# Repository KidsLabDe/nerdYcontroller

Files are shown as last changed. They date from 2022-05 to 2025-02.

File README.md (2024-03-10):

# Innovative Lernplatine mit Raspberry Pi Pico für angehende Programmierer

Diese benutzerfreundliche Platine ist speziell darauf ausgelegt, einen Raspberry Pi Pico aufzunehmen, und bietet eine interaktive Plattform, um die Grundlagen der Programmierung und Elektronik spielerisch zu erlernen.

**Hauptmerkmale:**

- **Vielseitiger Raspberry Pi Pico-Sockel:** Im Herzen der Platine befindet sich ein dedizierter Sockel, der perfekt für den Raspberry Pi Pico geeignet ist. Dies ermöglicht eine einfache Integration und eine robuste Verbindung.

- **Farbenfrohe LED-Anzeige:** Ausgestattet mit vier leuchtenden LEDs in verschiedenen Farben, bietet unsere Platine eine visuelle Rückmeldung für Programmierprojekte. Diese LEDs können für eine Vielzahl von Projekten programmiert werden, von einfachen Blinkmustern bis hin zu komplexeren Sequenzen.

- **Integrierter Neigungssensor:** Mit dem eingebauten Neigungssensor können Nutzer Bewegung und Ausrichtung in ihre Projekte einbeziehen. Dieser Sensor eröffnet spannende Möglichkeiten für interaktive Spiele und Experimente.

- **Kompakter Lautsprecher:** Ein kleiner, aber leistungsstarker Lautsprecher ermöglicht es, akustische Elemente in Projekte zu integrieren. Von einfachen Tonsignalen bis hin zu komplexen Melodien können die Nutzer ihre Kreativität voll ausleben.

- **Touch-Sensoren:** Die Platine verfügt über empfindliche Touch-Sensoren, die eine neue Dimension der Interaktivität bieten. Diese können für eine Vielzahl von Anwendungen genutzt werden, von Steuerelementen für Spiele bis hin zu kreativen musikalischen Experimenten.

- **Ideal für DIY-Gamecontroller:** Diese Platine ist nicht nur ein Lernwerkzeug, sondern auch eine Grundlage für den Bau eigener Gamecontroller. Nutzer können die vorhandenen Sensoren und Ausgänge verwenden, um einzigartige und individuelle Spieleerlebnisse zu schaffen.

**Anwendungsbereiche:**

Diese Platine ist ideal für Bildungseinrichtungen, Maker und alle, die einen praktischen und unterhaltsamen Einstieg in die Welt des Programmierens suchen. Sie bietet eine solide Grundlage für Projekte in den Bereichen Robotik, Spieleentwicklung und interaktive Kunst.

# Zusammenbau und erster Start

**Merke: Das Zusammenbauen ist nicht schwer - sie beim Löten zu brennen schmerzt dagegen sehr!** 

Daher immer auf die Finger obacht geben und den Lötkolben sicher ablegen!

## 1. Alles was du brauchst!

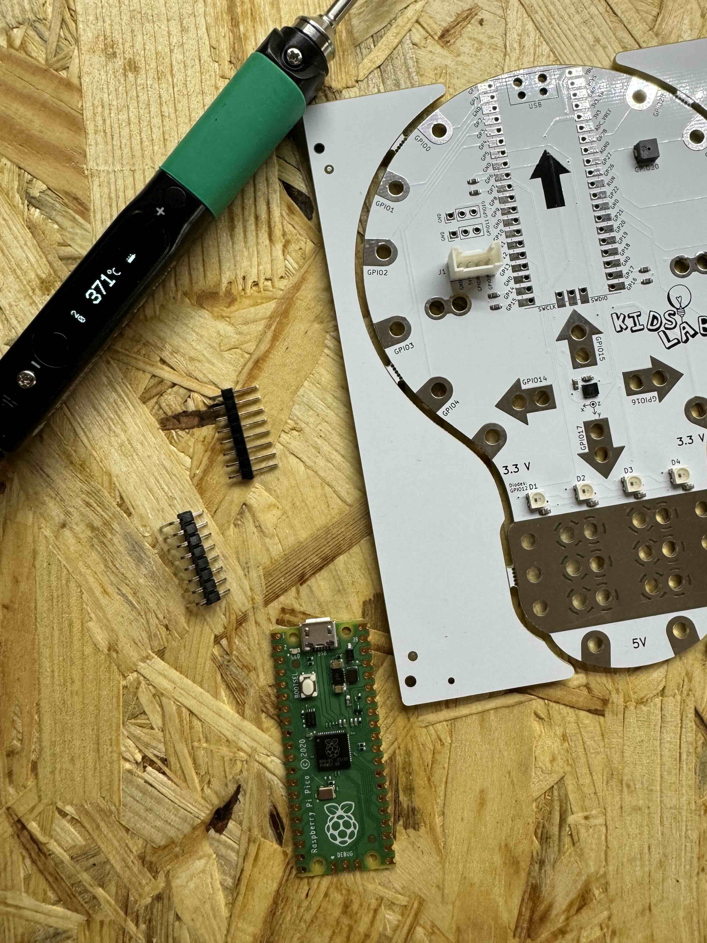
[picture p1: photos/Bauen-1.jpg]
Übersicht der Teile


- Lötkolben, Lötzinn etc.
- 2 "Header" - die nutzen wir, um den Pico richtig auf der Platine zu platzieren. Im Notfall gehen auch 2 Büroklammern...
- einen [Raspberry Pico](https://www.berrybase.de/raspberry-pi-pico-rp2040-mikrocontroller-board) (oder [Pico W](https://www.berrybase.de/raspberry-pi-pico-w-rp2040-wlan-mikrocontroller-board))

## 2. Richtig platzieren

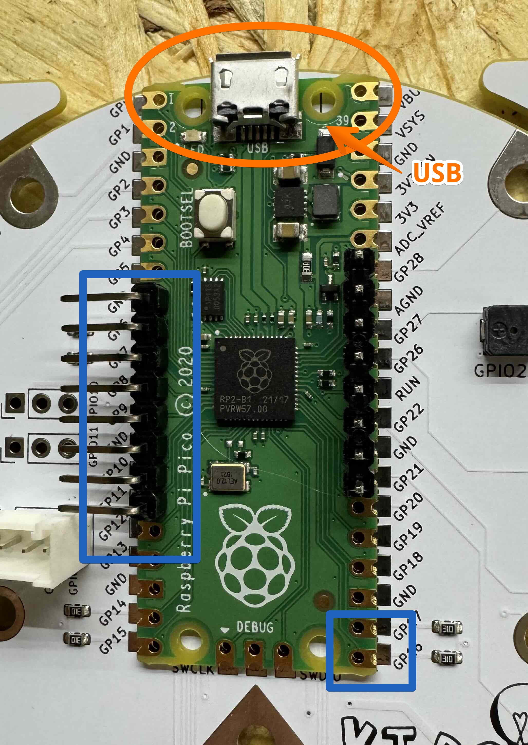
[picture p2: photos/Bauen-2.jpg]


Lege den Pico auf die Platine. 

** Achtung - der USB-Stecker muss oben sein! **

Bitte achte auch darauf, dass der Pico nicht verschoben ist.

## 3. Let's Löt!

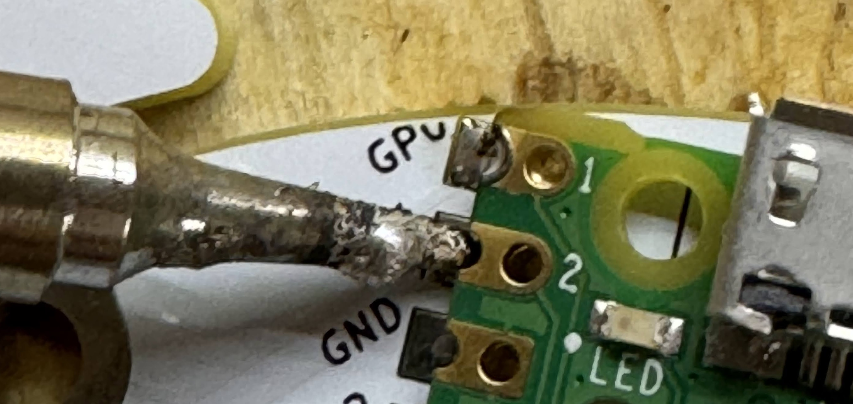
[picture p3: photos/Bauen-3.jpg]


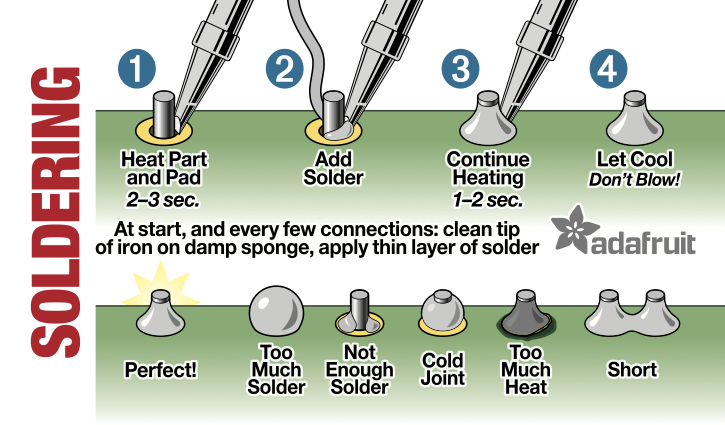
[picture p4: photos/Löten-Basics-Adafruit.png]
Lötes Basics

(Danke an Adafruit!)

- Lötkolben aufheizen
- Lötstelle mit Spitze berühren - am besten vor der Seite
- Etwas lötzinn zugeben
- 2-3 Sekunden warten!
- Jetzt etwas mehr Lötzinn von oben zugeben, es schmilzt an der Platine

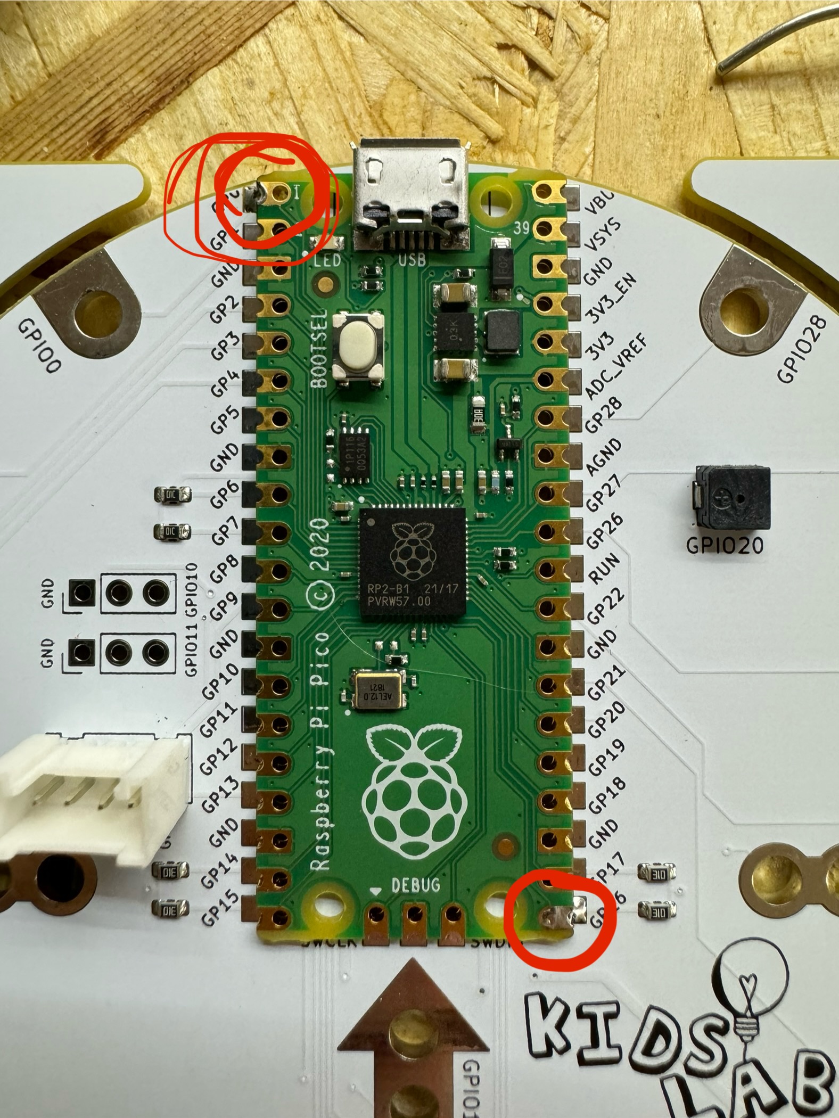
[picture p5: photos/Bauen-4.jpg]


Zuerst 2-3 Pins anlöten, zum Beispiel links oben und rechts unten - dann ist der Pico fest und du kannst die Header entfernen.

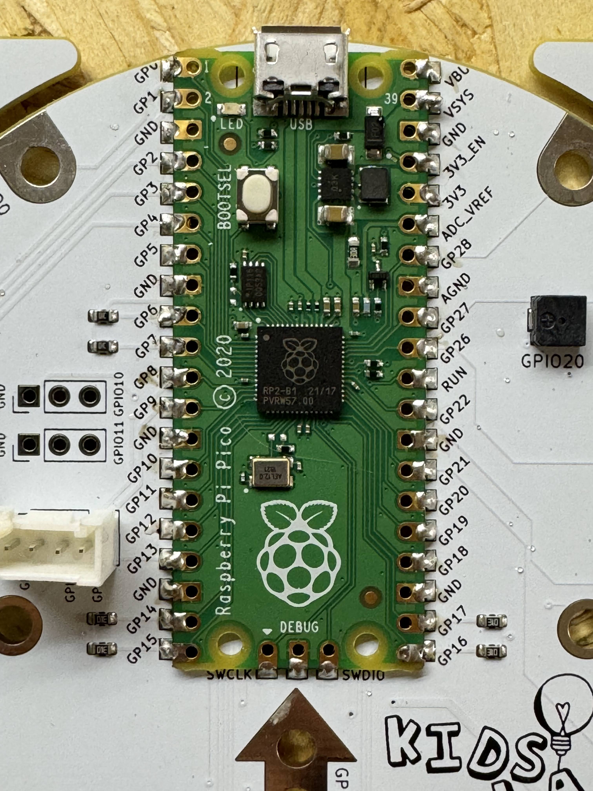
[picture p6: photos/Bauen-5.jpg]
Fertig gelötet


So sieht es aus, wenn alles fertig ist!

## 4. Anschließen und Software aufspielen!

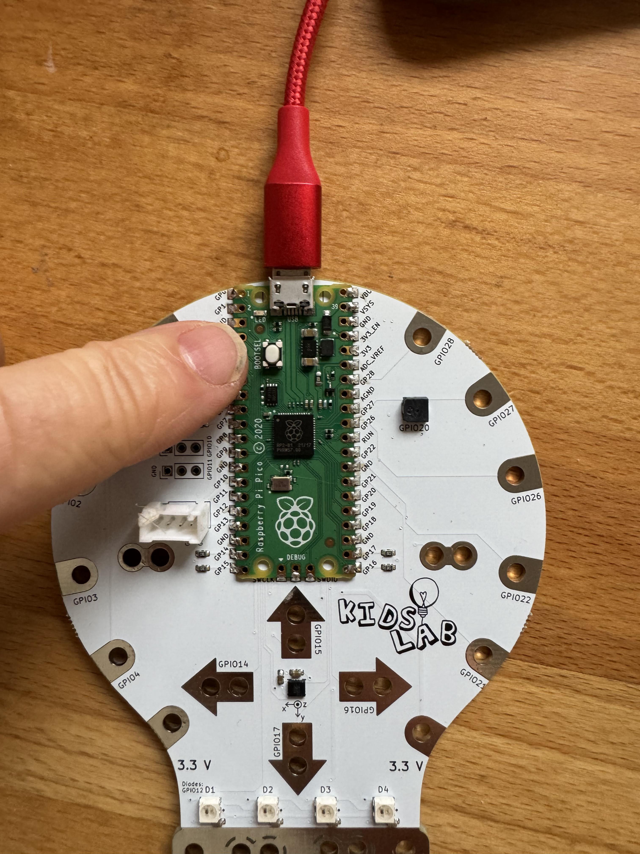
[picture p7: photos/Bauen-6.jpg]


- Stecke den Pico mit einem Micro-USB Kabel am Computer an.
- Wenn er neu ist, sollte er sofort wie ein USB-Stick auftauchen
- Wenn nicht, halte beim Anstecken die kleine weiße Taste "BOOTSEL" gedrückt.

So sieht das auf dem Mac aus:
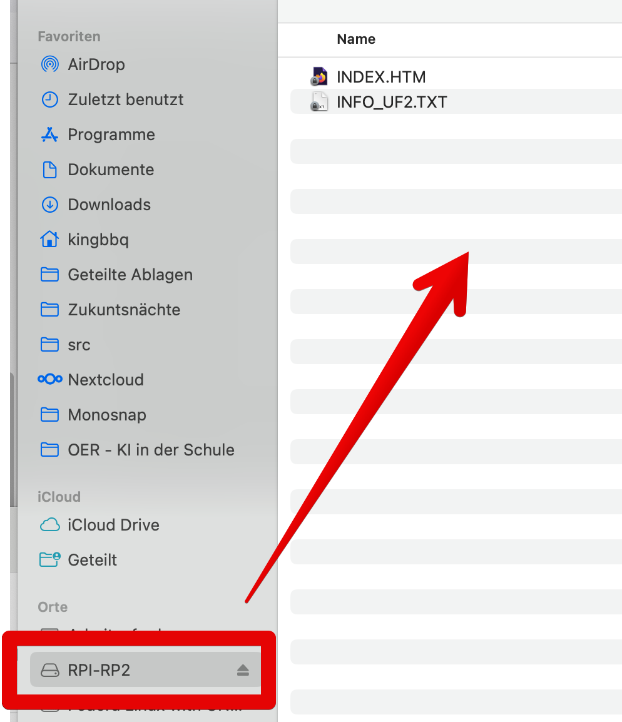
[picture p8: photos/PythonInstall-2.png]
Install 1

(Bei Windows ein bisschen anders...)

Jetzt fehlt nur noch die "Firmware" - das ist die Basis-Software, damit der Pico Python sprechen kann: zusätzlich habe ich noch einen Beispiel-Python-Code drauf gemacht, dass es blinkt etc.

1. Lade diese Datei runter: https://github.com/KidsLabDe/PicoKrokoBirne/blob/main/firmware/PicoKrokoBirne.uf2
2. Kopiere sie auf die Pico im Finder / Explorer. Das geht meistens per Drag&Drop
3. Fertig!

Die PicoKrokoBirne sollte jetzt fröhlich bunt drauf losblinken!

## Anpassen und los programmieren!

Der Pico erscheint nun wiederum als USB-Laufwerk, diesmal heißt er "CIRCUITPY".
Dort findest du die Datei "code.py" - da drin passiert die Magie!

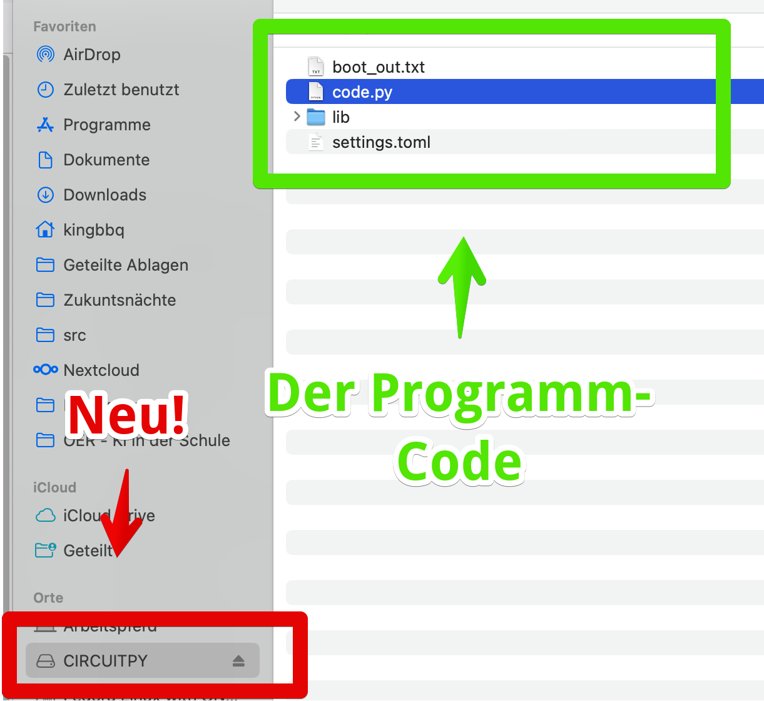
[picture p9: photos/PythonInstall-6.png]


Als Editor empfehle ich dir den Mu-Editor: https://codewith.mu

Viel Spaß!

# Kontaktdaten

Du hast die Glühbirne als Visitenkarte bekommen? Sehr gut! 

Meine Kontaktdaten:

- Gregor Walter
- [gregor@kidslab.de](mailto:gregor@kidslab.de
- Telefon / WhatsApp: 0821-99951920 
- Mehr Infos über das gemeinnützige [KidsLab](https://kidslab.de) 

Ich freue mich auf deinen Anruf / eMail / Nachricht 🤖

Glühbirne-v1

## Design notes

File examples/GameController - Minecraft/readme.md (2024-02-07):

# GameController - Minecraft Version

Dieser Code ist für ein Minecraft-Makro-Keyboard: Du drückst eine Taste und es schickt ein Kommando los, also zum Beispiel um den Gamemode zu wechseln:

`/gamemode 1`

Es wird zusätzlich nach dem "/" für den Kommando-Modus kurz gewartet.

Zum Anpassen der einzelnen Kommandos einfach diesen Teil hier anpassen:

```python
# Hier sind die einzelnen PINS (Tasten)  definiert und die dazu gehörigen Befehle
buttons = {
    board.GP15: "gamemode 1\n",
    board.GP14: "gamemode 2\n",
    board.GP13: "gamemode 3\n",
    board.GP12: "gamemode 4\n",
}
```

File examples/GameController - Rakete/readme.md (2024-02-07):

# GameController - Rakete

Hier ein Beispiel für die Rakete (siehe original: https://github.com/openlab-aux/SchaufensterRakete) - zu sehen im OpenLab zu Augsburg im Schaufenster.

Besonderheiten: 

- Es gibt einen TimeOut - wenn die Rakete 90 Sekenden nicht benutzt wird, wird zuerst 2 mal "enter" gedrückt, um das Spiel wieder zu starten.

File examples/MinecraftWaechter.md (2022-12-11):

# Lautstärkemesser & Minecraft-Abschalter

Wenn wir mit KidsLab in live Minecraft-Workshops machen, wird es manchmal sehr laut: die Emotionen kochen hoch und es ist ja auch alles super aufregend! Aber die Ohren der Mentoren leiden manchmal sehr unter diesen Ausbrüchen.

Daher haben wir mit der PicoKrokoBirne einen Lautstärkemesser erfunden, der automatisch die Emotionen der Kids runterfährt: er friert alle in Minecraft ein, sobald es zu laut wird. Wie das Damals der [Herr Ivan Pertowitsch Pawlow](https://de.wikipedia.org/wiki/Iwan_Petrowitsch_Pawlow) mit seinen Hunden gemacht hat, lassen sich der Geräusch-Ausstoß der Kids vielleicht auch regeln.

## Was brauchst Du?

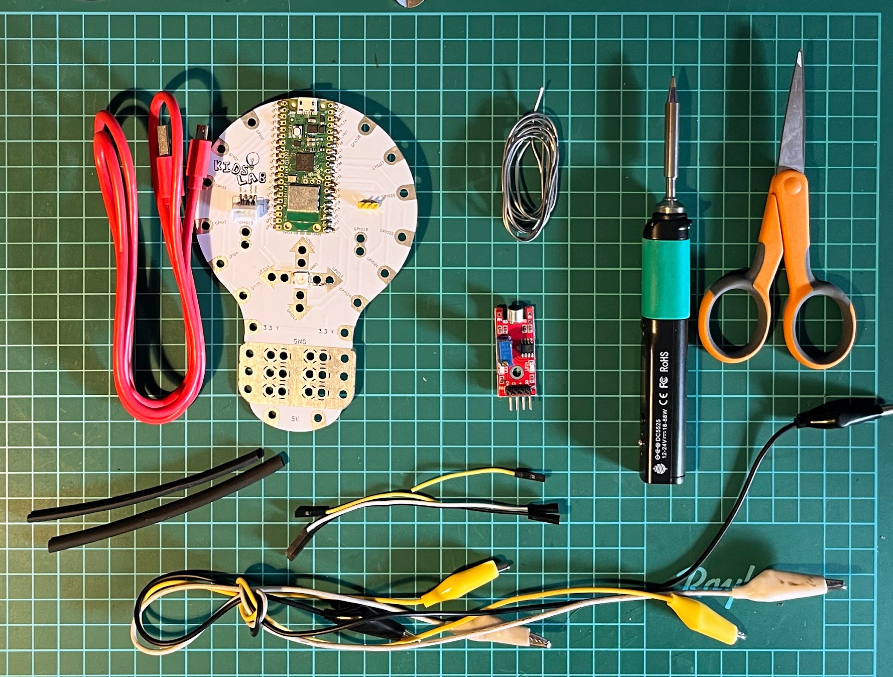
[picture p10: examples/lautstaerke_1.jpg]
lautstaerke_1


### Material

- PicoKrokoBirne mit Raspi Pico
- Lautstärke-Model (z.B. dieses [KY-038](https://sensorkit.joy-it.net/de/sensors/ky-038) gibts zum Beispiel hier: [Amazon AZ KY-038](https://amzn.to/3PhWPC4))
- Krokoklemmen & JumperKabel
- NeoPixel LED (optional)

## Vorbereitung

Bastel Dir aus den Krokoklemmen und JumperKabel die passenden Adapter, um das Lautstärke-Modul an die PicoKrokoBirne anzuschließen:

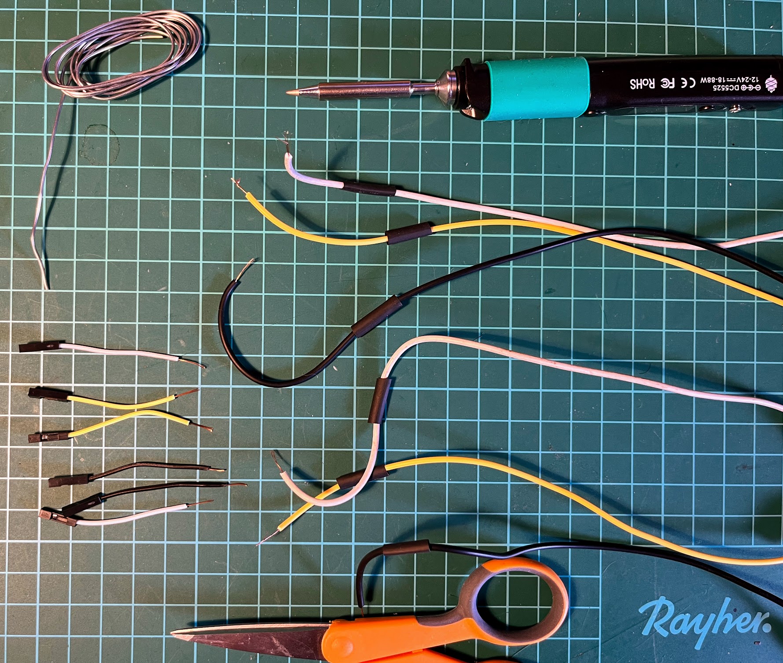
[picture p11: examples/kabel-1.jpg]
kabel-1


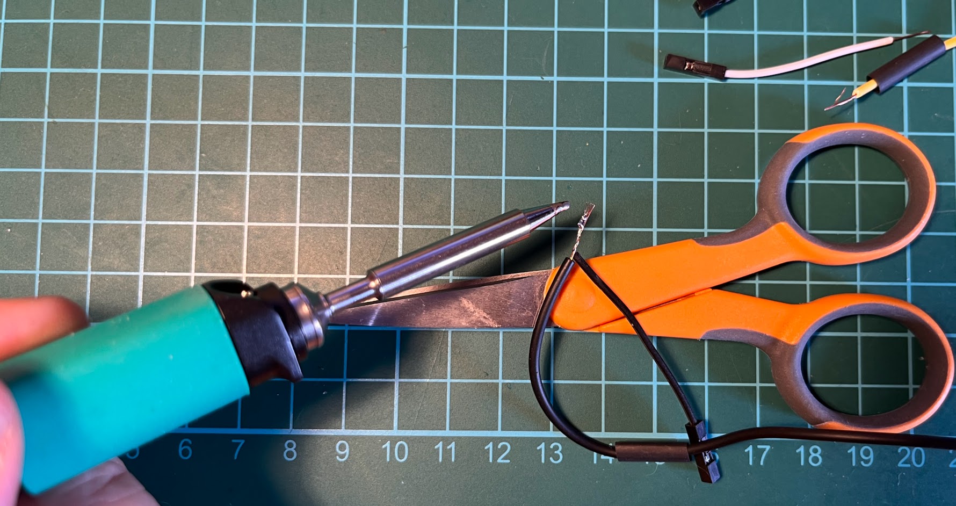
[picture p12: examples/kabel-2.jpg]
kabel-2


## Anschließen

- "+" kommt auf 3.3v
  - Der Sensor kann mit 3.3 oder 5 Volt betrieben werden - es muss aber jeweils die Empfindlichkeit anpassen

- "G" kommt auf GND
- D0 kommt auf einen digitalen Eingang, zum Beispiel GPIO0 

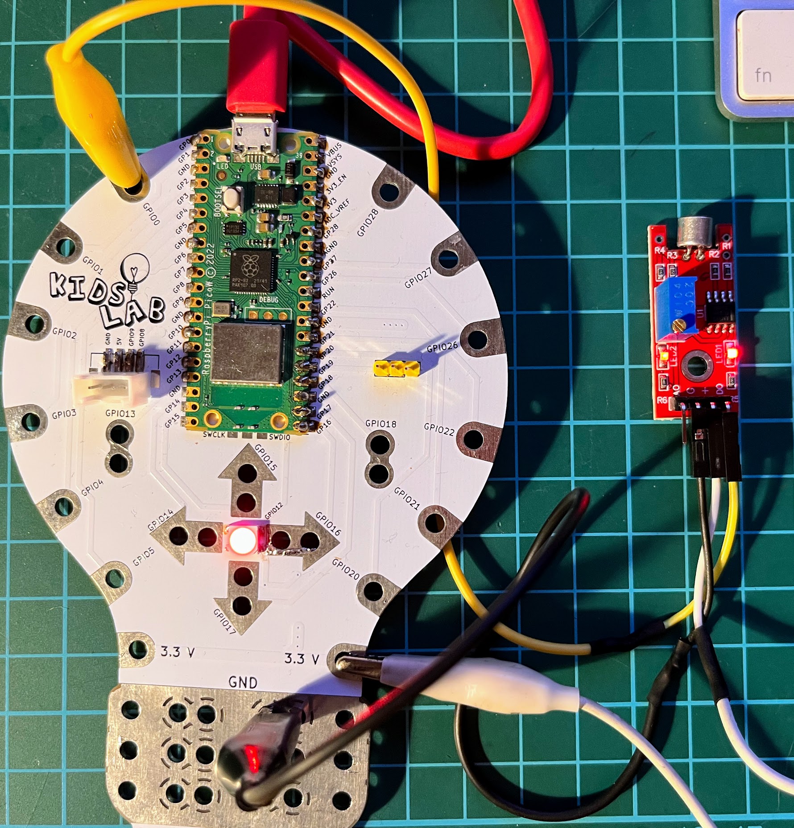
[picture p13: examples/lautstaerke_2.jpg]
lautstaerke_2


## Programmierung

### Lautstärke Messung

Das hat sich schwieriger herausgestellt als gedacht. Der Sensor sollte eigentlich am A0-Anschluss ein analoges Signal liefern: desto lauter, desto höher sollte die Spannung sein. Leider funktionierte das überhaupt nicht wie erwartet. Die Spannung veränderte sich nur sehr wenig, zu wenig, um die Lautstärke vernünftig zu messen.

Zuerst muss ich den Pin einrichten:

```python
import time
import board
from board import *
from digitalio import DigitalInOut, Direction, Pull

switch = DigitalInOut(board.GP0)
switch.direction = Direction.INPUT
switch.pull = Pull.DOWN
```

Der Sensor hat 2 Ausgänge: zusätzlich zu dem analogen auch einen digitalen: über den Dreh-Schalte (Potentiometer) auf der Platine, lässt sich eine Schwelle einstellen. Wenn diese überschritten ist, wird ein digitales Signal (0 Volt, 3,3 Volt) ausgegeben. Wenn man das "sammelt", das heißt über einen bestimmten Zeitraum zusammenzählt, erhält man einen guten Wert.

```python
while True:
		noiseLevel = 0;
    for x in range(100000):
        if switch.value:
            noiseLevel = noiseLevel +1
    if noiseLevel < 500:
        pixels.fill(GREEN)
    elif noiseLevel < 1500:
        pixels.fill(YELLOW)
    elif noiseLevel < 4000:
        pixels.fill(RED)
    else:
        pixels.fill(PURPLE)
    pixels.show()      
```

### Lautstärke kalibieren

Damit der Sensor richtig anspricht, müssen wir ihn noch Kalibrieren, also beibringen, was genau "zu laut" ist:

- Die **LED2** zeigt an, ab der Sensor anschlägt
- An der Schraube auf dem kleinen blauen Kästchen kannst du sie einstellen
- Drehe so lange, bis die LED ausgeht 
- Jetzt vorsichtig sol lange, bis sie blinkt, wenn es laute Geräusche gibt  

### Minecraft User einfrieren

Jetzt fehlt noch noch eines: wenn es zu laut ist, sollen die User in Minecraft eingefroren werden. Das machen wir über die Funktion des Pico, die HID heißt: er kann so tun, als ob er eine Tastatur ist. 

```python
    else:
        pixels.fill(PURPLE)
        typeIt("/der Befehl zum Einfrieren")
```

Die PicoKrokoBirne also nur noch am Rechner der Mentors anschließen - und sobald es zu laut wird....

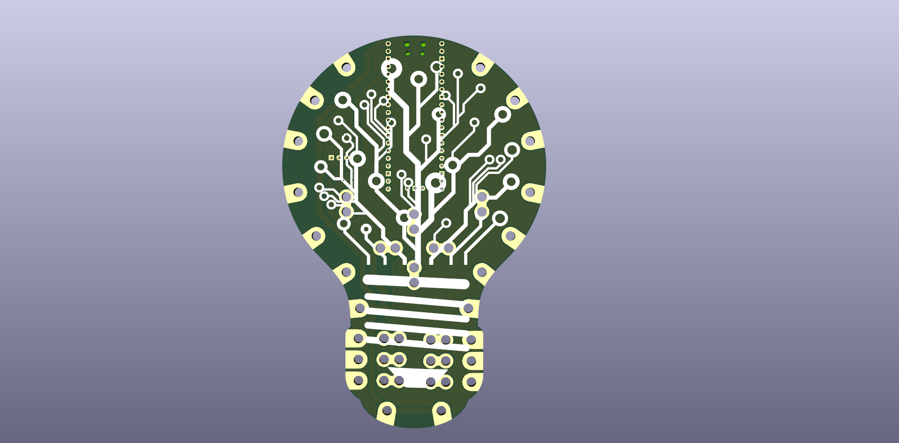
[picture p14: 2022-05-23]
kidslab-lamp_screenshot_backDesign_0.7.png

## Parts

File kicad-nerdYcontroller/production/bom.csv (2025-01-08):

Designator | Footprint | Quantity | Value | LCSC Part #
BZ301 | FUET-5020 | 1 | Buzzer-FUET-5020 | C391029
C101, C113, C114, C304 | 0603 | 4 | 100nF | C14663
C102, C103 | 0603 | 2 | 22pF | C1653
C104, C105, C106, C107, C108, C109, C110, C301, C302, C401, C402, C403, C404, C405, C406, C407, C408, C409, C410, C411, C412, C413, C414, C415, C416, C417, C418, C419, C420, C421, C422, C423, C424, C425 | 0402 | 34 | 100nF | C56392
C111 | 0603 | 1 | 10uF | C96446
C112, C115, C303, C305 | 0603 | 4 | 1uF | C15849
C201, C202 | 0805 | 2 | 10uF | C710989
C203 | 0603 | 1 | 1nF | C1588
D201, D203 | D_SOD-123 | 2 | B5817W | C2909923
D202 | WSON-6_1.5x1.5mm_P0.5mm | 1 | PRTR5V0U2F | C2937001
D301 | 0603 | 1 | KT-0603R | C2286
D401, D402, D403, D404, D405, D406, D407, D408, D409, D410, D411, D412, D413, D414, D415, D416, D417, D418, D419, D420, D421, D422, D423, D424, D425 | LED_WS2812B-2020_PLCC4_2.0x2.0mm | 25 | WS2812B-2020 | C965555
J201 | JST_PH_S2B-PH-SM4-TB_1x02-1MP_P2.00mm_Horizontal | 1 | S2B-PH-SM4-TB | C295747
J301, J302 | PinHeader_2x03_P2.54mm_Vertical_SMD | 2 | Conn_02x03_Odd_Even | C192301
J303 | ZX-HY2.0-4PLT | 1 | ZX-HY2.0-4PLT | C7429562
J304 | SAMTEC_HLE-115-02-F-DV | 1 | HLE-115-02-F-DV
P201 | USB_C_Receptacle_GCT_USB4110 | 1 | USB_C_Plug_USB2.0 | C5143397
Q301 | SOT-23 | 1 | DDTC113ZCA | C151437
R101, R102, R105, R307 | 0603 | 4 | 1k | C21190
R103, R104 | 0603 | 2 | 27R | C25190
R201, R202 | 0603 | 2 | 5k1 | C23186
R203 | 0603 | 1 | 100 | C22775
R301, R302 | 0603 | 2 | 10k | C25804
R303, R304, R305, R306 | 0603 | 4 | 1M | C105578
R308 | 0603 | 1 | 33k | C25593
R309 | 0603 | 1 | 330R | C22104
S101 | SW_TS-1187A-B-A-B | 1 | TS-1187A-B-A-B | C318884
U101 | QFN-56-1EP_7x7mm_P0.4mm_EP3.2x3.2mm | 1 | RP2040
U102 | SOIC-8_5.23x5.23mm_P1.27mm | 1 | W25Q128JVS | C97521
U201 | SOT-223-3_TabPin2 | 1 | AMS1117-3.3 | C6186
U301 | LGA-14_3x2.5mm_P0.5mm_LayoutBorder3x4y | 1 | LSM6DS3TR-C | C967633
U302 | LMA3722T421-OA5 | 1 | LMA3722T421-OA5 | C5373233
Y101 | Crystal_SMD_3225-4Pin_3.2x2.5mm | 1 | Crystal_GND24 | C9002

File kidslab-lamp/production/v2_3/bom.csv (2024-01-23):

Designator | Footprint | Quantity | Value | LCSC Part #
BZ1 | Buzzer-FUET-4020 | 1 | Buzzer-FUET-4020 | C391027
C4, C5, C6, C7, C8, C9 | 0603 | 6 | 100nF | C14663
D1, D2, D3, D4 | WS2812B-Mini | 4 | WS2812B-Mini | C527089
J1 | HY-4A-THT | 1 | HY-4A | C146064
R1, R2, R3, R4 | 0603 | 4 | 1M | C105578
R5, R6 | 0603 | 2 | 10k | C25804
U2 | LGA-14_3x2.5mm_P0.5mm_LayoutBorder3x4y | 1 | LSM6DS3TR-C | C967633

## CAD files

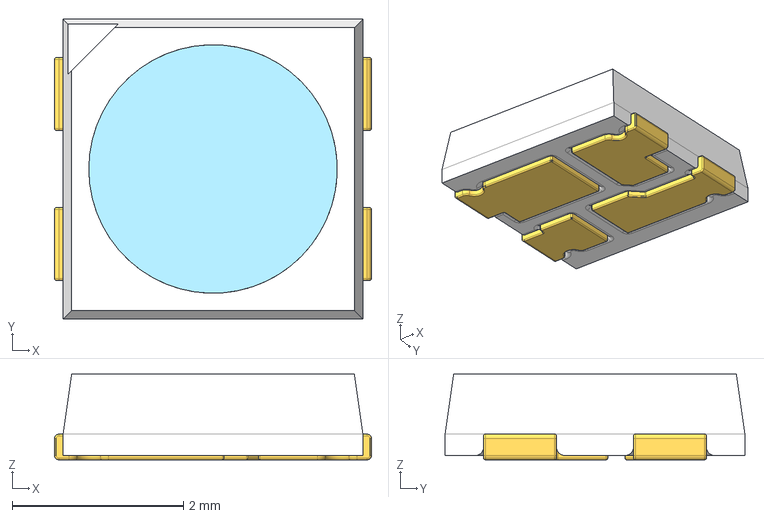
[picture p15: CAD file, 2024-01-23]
kidslab-lamp/3D/SMD3535 RGB.stp
3.70 x 3.50 x 1.00 mm

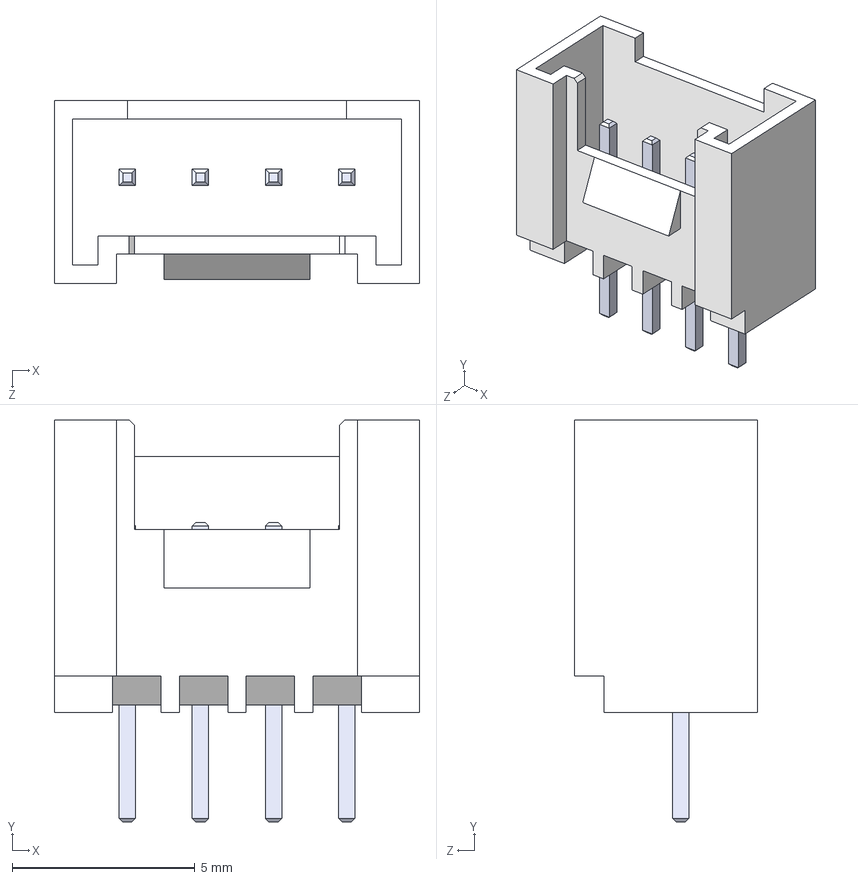
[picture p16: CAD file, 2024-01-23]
kidslab-lamp/3D/Grove Connector.STEP
10.0 x 11.0 x 5.00 mm

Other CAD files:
kidslab-lamp/KiCad-RP-Pico/SketchUp Model/Pico.skp
kidslab-lamp/footprints/KiCad-RP-Pico/SketchUp Model/Pico.skp

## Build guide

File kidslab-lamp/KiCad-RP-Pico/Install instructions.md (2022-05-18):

# Install instructions

## 1. Copy the files locally

Copy the `RP-Pico Libraries` folder wherever you like on your computer.

## 2. Install the Raspberry Pi Pico board schema symbol

Use the `KiCad | Preferences | Manage Symbol Libraries...` command to manage the symbol library:



then select the global tab and click on the folder button:



navigate to the `RP-Pico Libraries` folder, select the `MCU_RaspberryPi_and_Boards.kicad_sym` file and open it:



et voilà, the first step is completed:



You can now close the symbol libraries manager window.

## 3. Install the Raspberry Pi Pico board footprint

You can use a similar approach to add the footprint to the footprint libraries manager, but I've found some issues that I've solved using the footprint editor, so here are the steps I suggest you to follow:

Open the footprint editor



wait for the footprints to load... then use the `File | Add Library` command:



confirm the `Global` choice:



and select the `MCU_RaspberriPi_and_Boards.pretty` folder (yes, the folder represent a footprint library on KiCad):



Now the library is installed on KiCad with the Raspberry Pi Pico footprint (double click on it to see it on the editor pane):



Don't close the windows as the next step start from here.

## 4. Install the Raspberry Pi Pico board footprint 3D visual

If not already open, open the the footprint editor

symbol library manager

double click on the `RPi_Pico_SMD_TH` footprint from the `MCU_RaspberriPi_and_Boards` library and then click on the `Footprint properties` icon:



In the footprint properties window, first select the `3D Settings` tab. Please note that the preview shows only the PCB board with the footprint added on step 3, without any 3D representation of the Raspberry Pi Pico board. Now click on the folder icon to add the 3D model:



Navigate to the `RP-Pico Libraries` folder, select the `Pico.wrl` file and wait until the model is shown in the right panel, then confirm with OK:



The model is already scaled and translated to match the footprint:



now close the `Footprint Properties` window, and the `Footprint Editor`, obviously saving the changes.

## Conclusion

Now that you've installed the schema and footprint and added the 3D model to the footprint, you can use the Raspberry Pi Pico board on your KiCad projects.

I've also added a test KiCad Project on the `Test` folder, that you can use to see an example of it.

Have fun!

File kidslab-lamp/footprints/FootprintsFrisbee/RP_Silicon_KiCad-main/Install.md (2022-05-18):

# Install KiCad libraries

## Manage Symbol Libraries

Accessed from the Preferences menu, add a new line with the +, give it a name and use the folder icon to point to the directory/folder where you have KiCadLibraries.

Manage Symbol Libraries screen shot


## Manage Footprint Libraries

Ditto! Accessed from the Preferences menu, add a new line with the +, give it a name and use the folder icon to point to the directory/folder where you have KiCadLibraries.

Manage Footprint Libraries screen shot


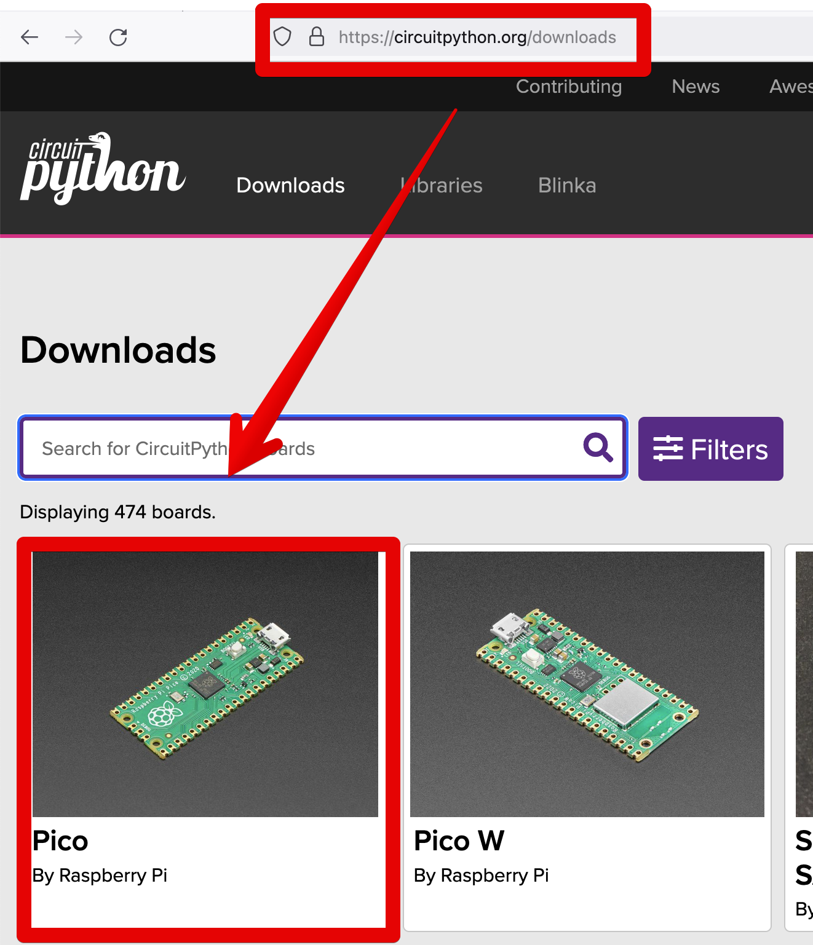
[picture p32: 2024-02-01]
photos/PythonInstall-3.png

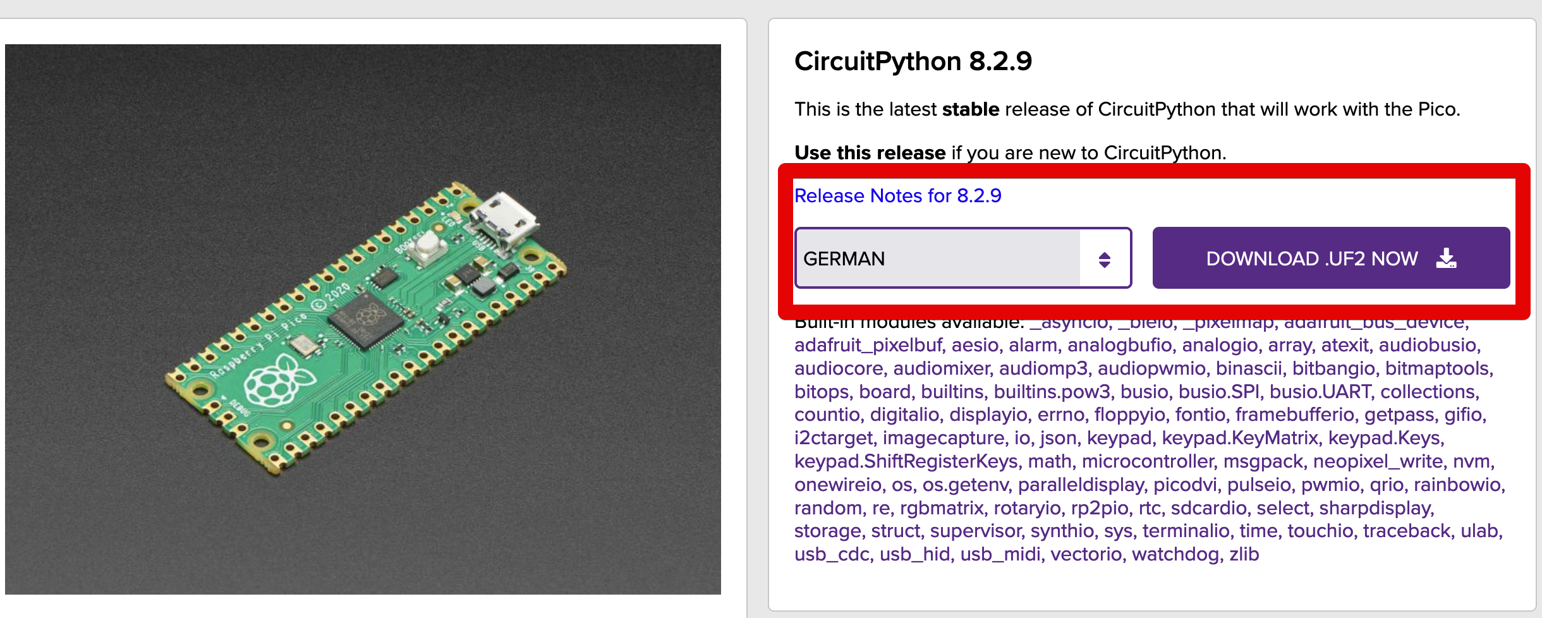
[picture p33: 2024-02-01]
photos/PythonInstall-4.png

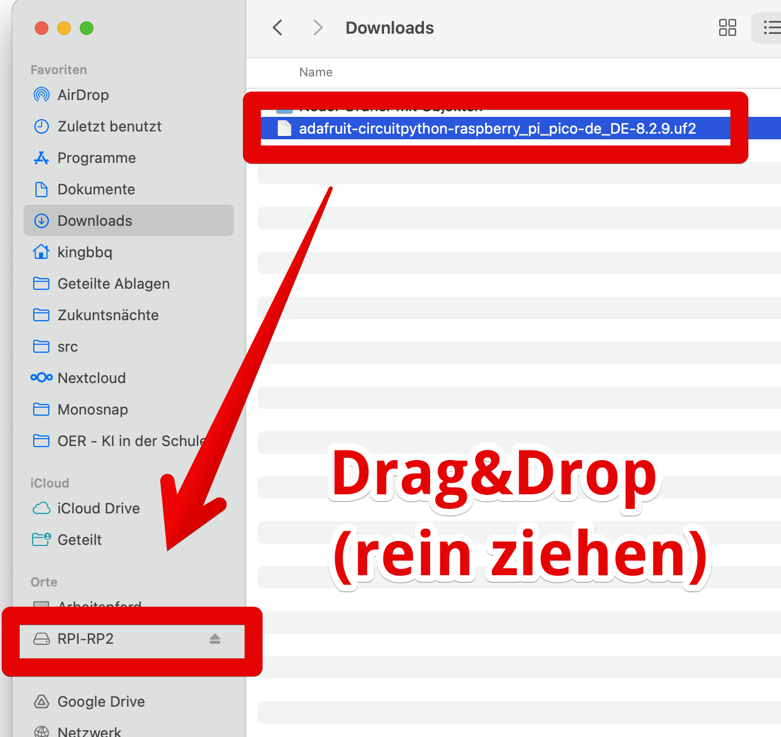
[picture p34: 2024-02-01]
photos/PythonInstall-5.png

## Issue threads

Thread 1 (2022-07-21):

3V / GND very close

KingBBQ, 2022-07-21:
while testing we had a few "shorts" - the 3v pins are very close to the GND plate.

strg-v, 2022-09-11:
Removed GPIO5 & GPIO20 and moved 3.3V up in order to prevent short circuits.

Closed 2022-09-11.

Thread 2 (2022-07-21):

Add QR Code with more info

KingBBQ, 2022-07-21:
Should we use a link like "Kidslab.de/Glühbirne" or the link to the github project? What do you reckon?

KingBBQ, 2022-07-21:
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

strg-v, 2022-09-11:
Added the QR-Code to the right of the Pi-Pico.

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

Closed 2022-09-11.

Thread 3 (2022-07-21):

How to solder the NeoPixel?

KingBBQ, 2022-07-21:
4 pins, it's not clear with pin is which...

strg-v, 2022-09-11:
Added silk screen markings indicated in the [datasheet](https://cdn-shop.adafruit.com/product-files/1138/SK6812+LED+datasheet+.pdf):

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

Closed 2022-09-11.

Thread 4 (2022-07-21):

Add orientation for the Pico

KingBBQ, 2022-07-21:
when soldering the picos to the pcb, 2 times i soldered them with the USB "down". Maybe add a arrow or such, to make the orientation clearer?

strg-v, 2022-09-11:
Added a box indicating the USB port location, as well as a big arrow pointing upwards ;)

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

Closed 2022-09-11.

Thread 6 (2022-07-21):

Add touch pull up resisitors

KingBBQ, 2022-07-21:
see:
https://github.com/microbit-foundation/microbit-v2-hardware/blob/main/V2/MicroBit_V2.0.0_S_schematic.PDF

for the 4 direction pins

strg-v, 2022-09-11:
I added four through hole resistor locations for 10MOhm resistors. R1-R4:

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

Closed 2022-09-11.

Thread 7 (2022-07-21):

2nd Servo connector (optional)

KingBBQ, 2022-07-21:
To be able to connect 2 servos at once over the header pins.

KingBBQ, 2022-07-26:
and please use pins 1-15 for the signal.
PiperMake supports these only in the UI.
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

KingBBQ, 2022-07-28:
testet the servo connection - works like a charm :)

strg-v, 2022-09-11:
I added another PWM connector to GPIO10 and moved the existing one to GPIO11.

Closed 2022-09-11.

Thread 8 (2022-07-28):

Which is the right component for grove?

KingBBQ, 2022-07-28:
this one?
https://www.reichelt.de/arduino-grove-universal-buchse-4-pin-90-10er-pack--grv-connec4pin90-p191136.html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

strg-v, 2022-09-11:
I used this one: https://www.mouser.de/ProductDetail/Seeed-Studio/114020163?qs=7MVldsJ5Uaz48D%2F3kIbRqg%3D%3D

Closed 2022-09-11.

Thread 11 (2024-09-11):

GP statt GPIO / Verwirrend

KingBBQ, 2024-09-11:
auf der platine des pico und im code heißen die Pins immer GP

auf der Glühbirne GPIO - verwirrend?

https://www.elektronik-kompendium.de/sites/raspberry-pi/2611051.htm

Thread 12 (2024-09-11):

Grove stecker - 2 & Belegung

KingBBQ, 2024-09-11:
- aktuell geht das auf GP8 und 9
- da ist aber dein Analog

https://www.elektronik-kompendium.de/sites/raspberry-pi/2611051.htm

ein zusätzlicher anschluss auf 26 / 27 ODER 28?

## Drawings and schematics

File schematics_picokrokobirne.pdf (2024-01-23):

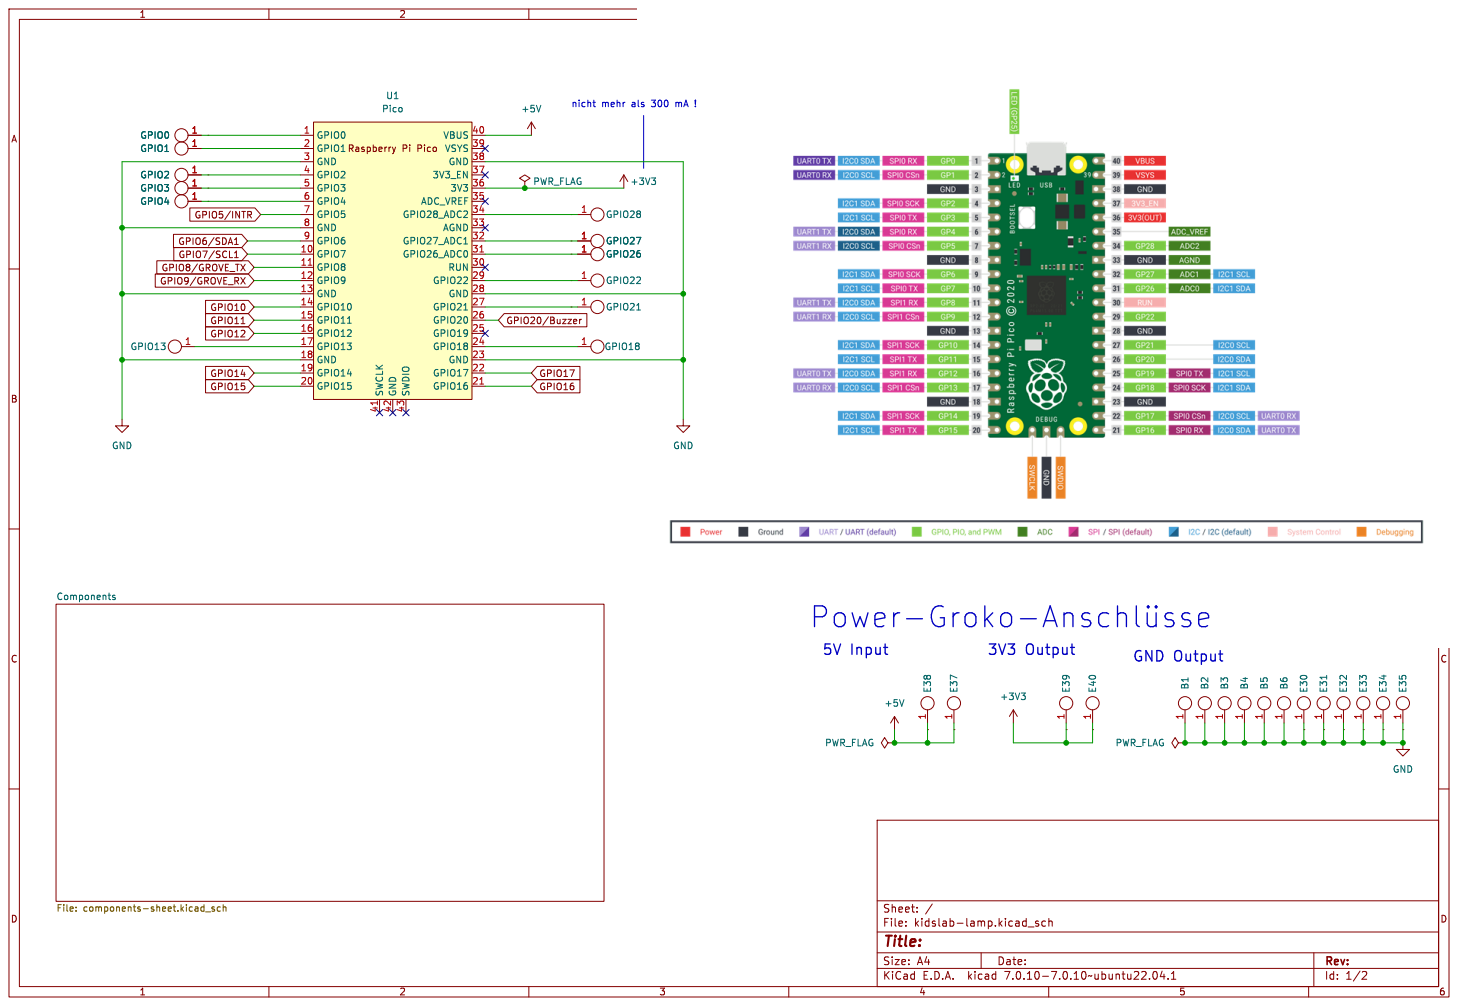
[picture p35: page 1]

Id: 1/2 Title: File: kidslab-lamp.kicad_sch Sheet: / Components File: components-sheet.kicad_sch

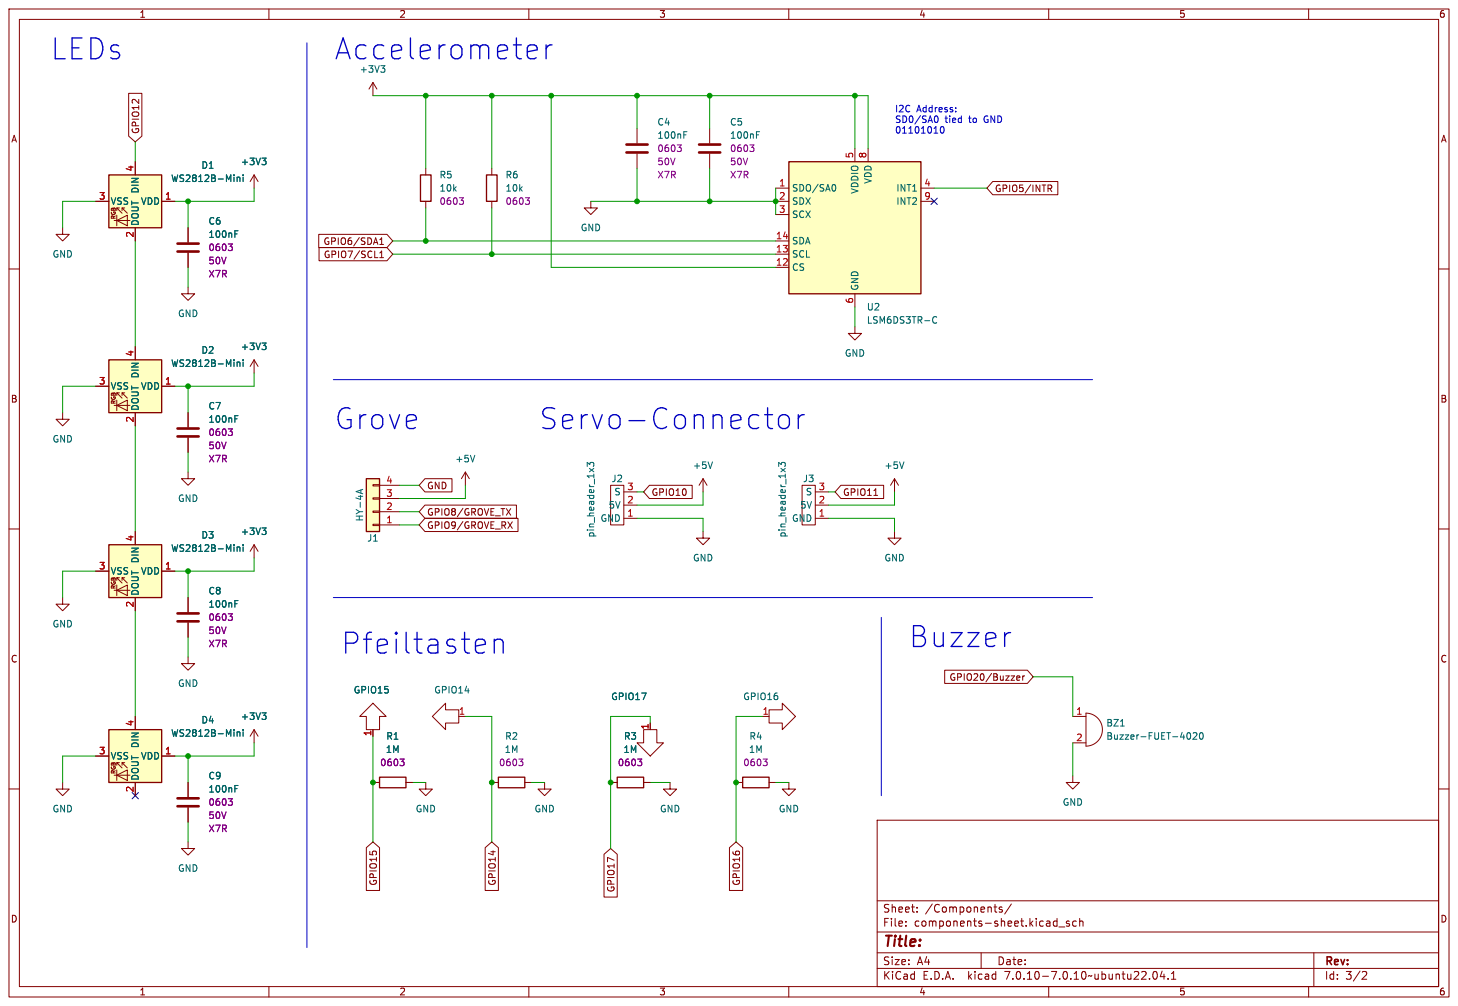
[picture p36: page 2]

I2C Address: SD0/SA0 tied to GND

Id: 3/2 Title: File: components-sheet.kicad_sch Sheet: /Components/

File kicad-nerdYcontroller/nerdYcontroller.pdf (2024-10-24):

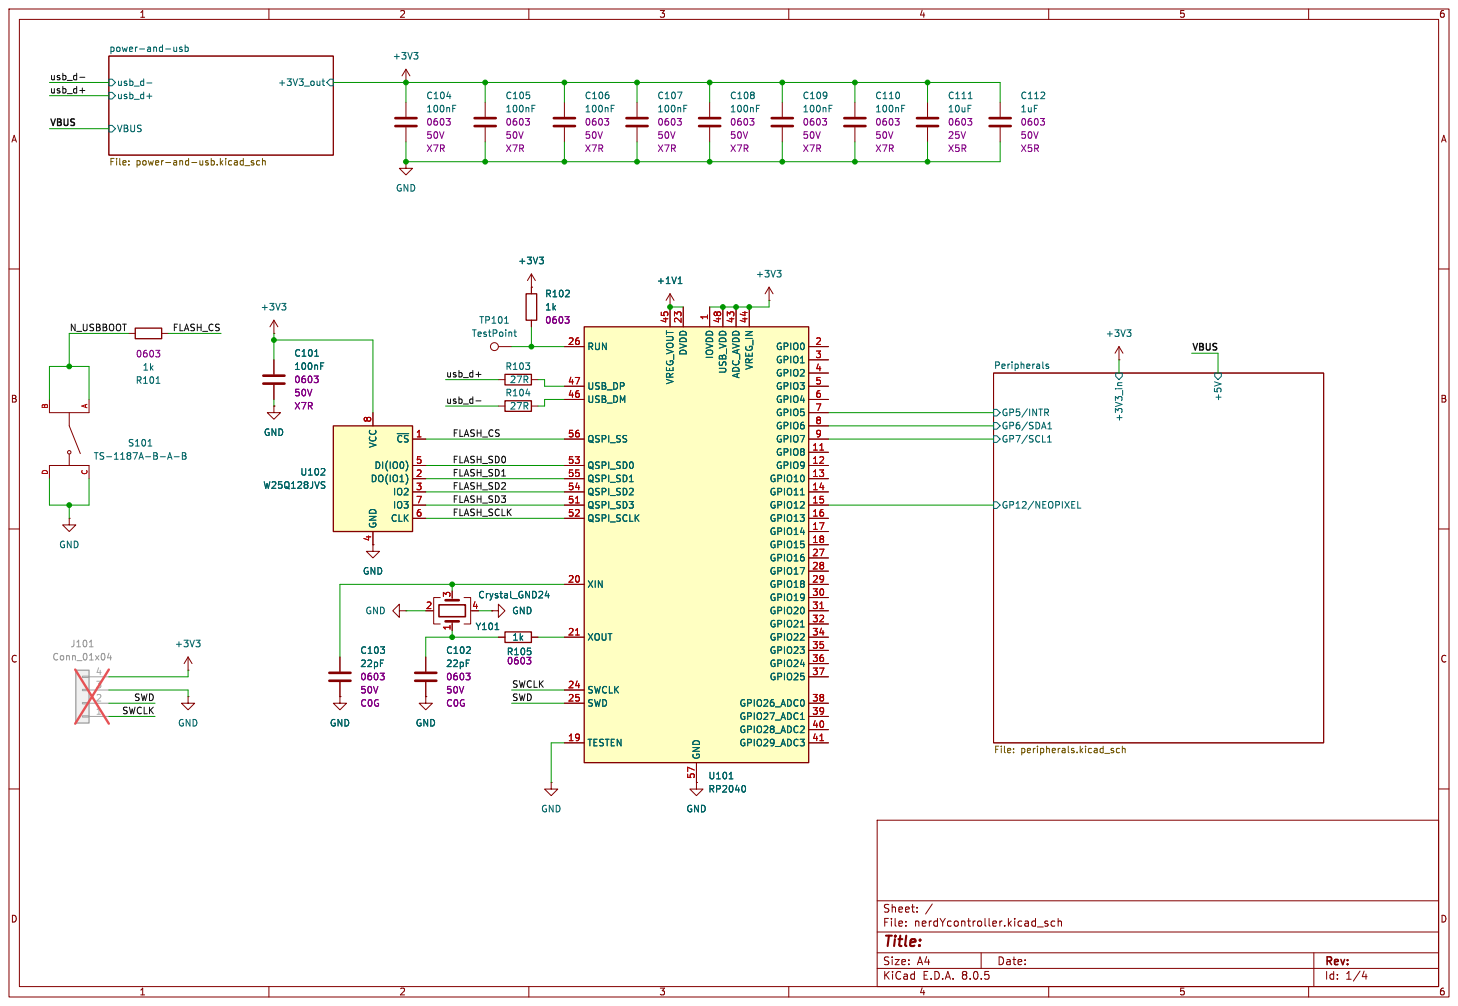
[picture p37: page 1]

1 GPIO8 11 GPIO9 12 GPIO10 13 GPIO11 14 GPIO12 15 GPIO13 16 GPIO14 17 GPIO15 18 TESTEN 19 GPIO0 2 XIN 20 XOUT 21 DVDD 23 SWCLK 24 SWD 25 RUN 26 GPIO16 27 GPIO17 28 GPIO18 29 GPIO1 3 GPIO19 30 GPIO20 31 GPIO21 32 GPIO22 34 GPIO23 35 GPIO24 36 GPIO25 37 GPIO26_ADC0 38 GPIO27_ADC1 39 GPIO2 4 GPIO28_ADC2 40 GPIO29_ADC3 41 ADC_AVDD 43 VREG_IN 44 VREG_VOUT 45 USB_DM 46 USB_DP 47 USB_VDD 48 GPIO3 5 QSPI_SD3 51 QSPI_SCLK 52 QSPI_SD0 53 QSPI_SD2 54 QSPI_SD1 55 QSPI_SS 56 GND 57 GPIO4 6 GPIO5 7 GPIO6 8 GPIO7 9 U101 RP2040 GND

1 GPIO8 11 GPIO9 12 GPIO10 13 GPIO11 14 GPIO12 15 GPIO13 16 GPIO14 17 GPIO15 18 TESTEN 19 GPIO0 2 XIN 20 XOUT 21 DVDD 23 SWCLK 24 SWD 25 RUN 26 GPIO16 27 GPIO17 28 GPIO18 29 GPIO1 3 GPIO19 30 GPIO20 31 GPIO21 32 GPIO22 34 GPIO23 35 GPIO24 36 GPIO25 37 GPIO26_ADC0 38 GPIO27_ADC1 39 GPIO2 4 GPIO28_ADC2 40 GPIO29_ADC3 41 ADC_AVDD 43 VREG_IN 44 VREG_VOUT 45 USB_DM 46 USB_DP 47 USB_VDD 48 GPIO3 5 QSPI_SD3 51 QSPI_SCLK 52 QSPI_SD0 53 QSPI_SD2 54 QSPI_SD1 55 QSPI_SS 56 GND 57 GPIO4 6 GPIO5 7 GPIO6 8 GPIO7 9 GND

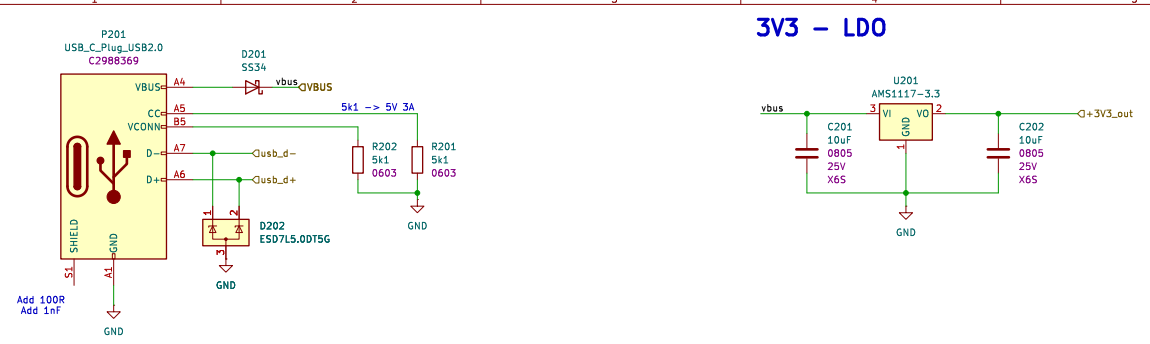
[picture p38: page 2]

Id: 2/4 Title: File: power-and-usb.kicad_sch Sheet: /power-and-usb/

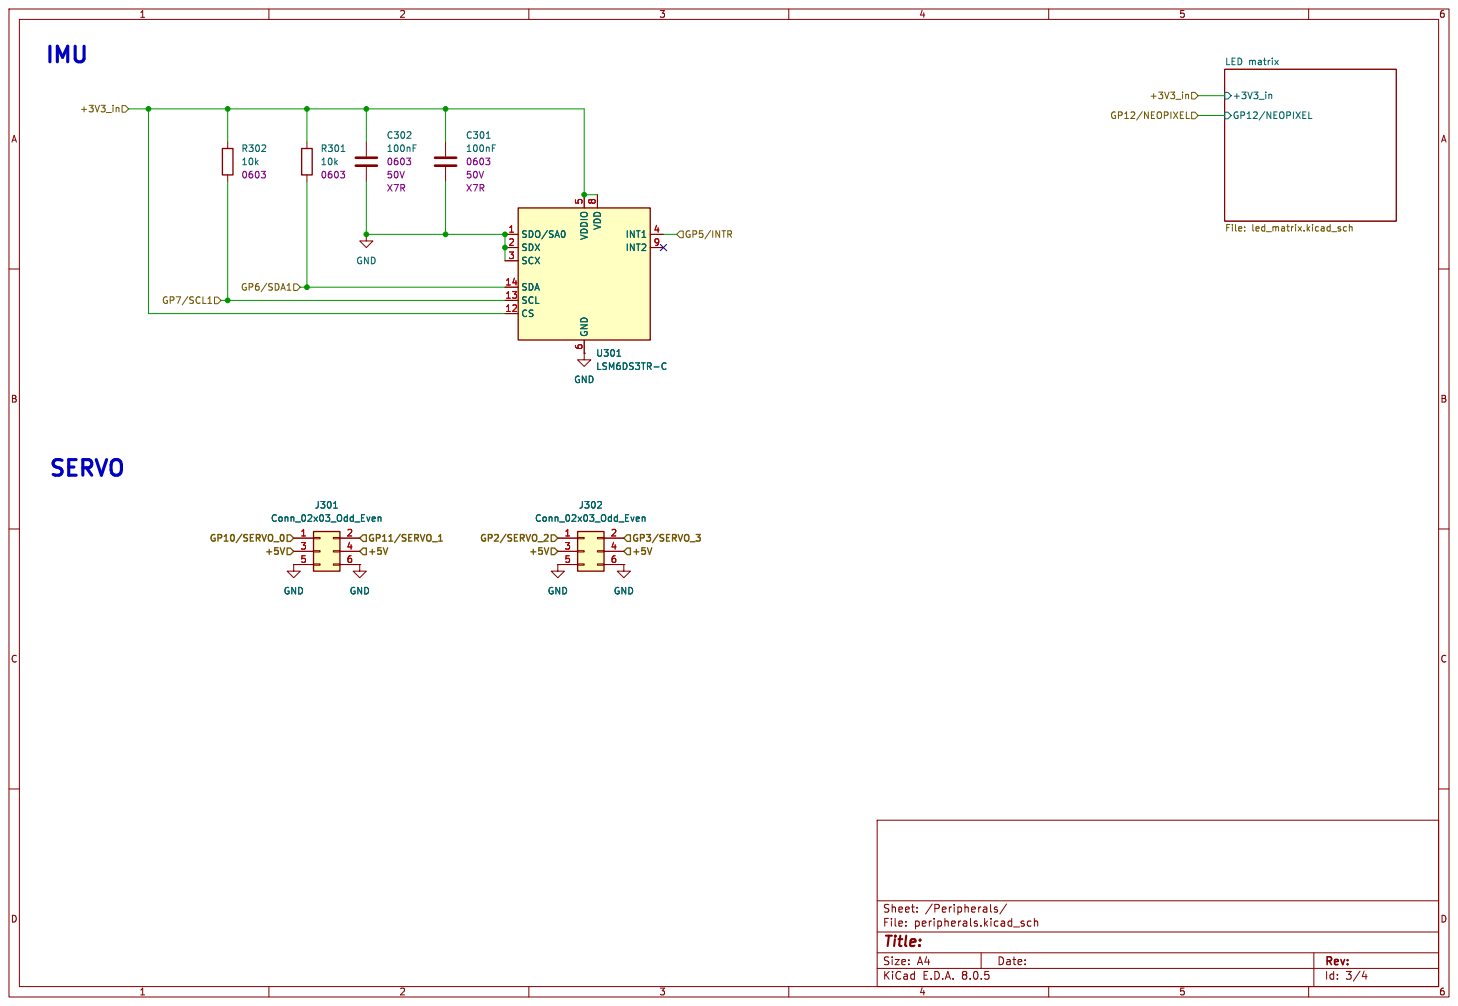
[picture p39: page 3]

Id: 3/4 Title: File: peripherals.kicad_sch Sheet: /Peripherals/

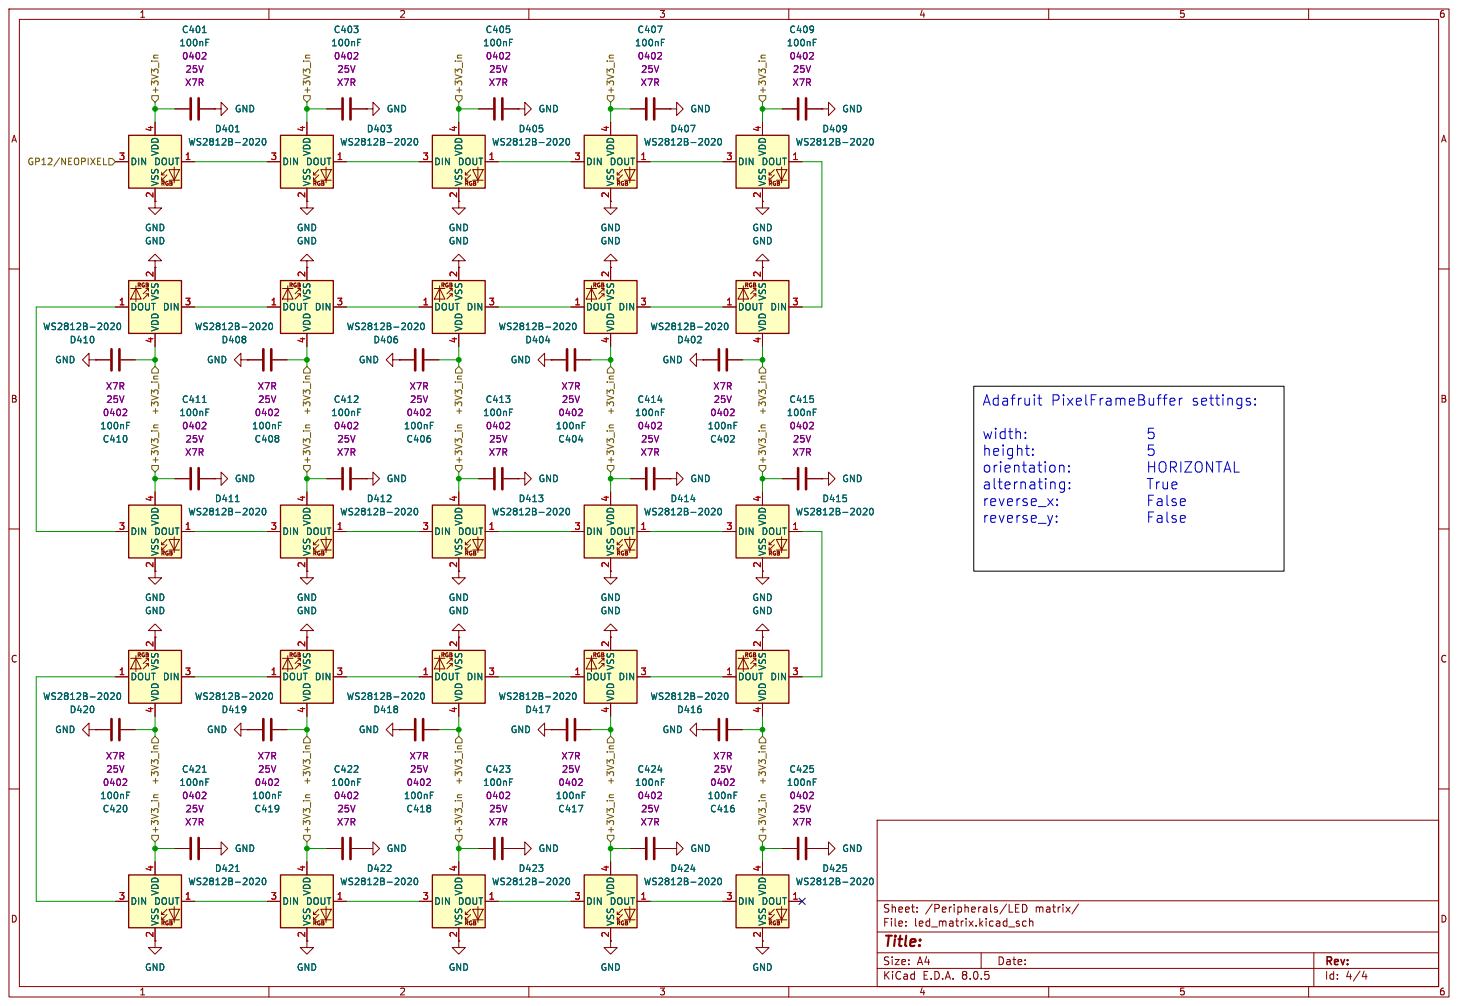
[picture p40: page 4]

4D409 WS2812B-2020 GND GND GND GND GND GND

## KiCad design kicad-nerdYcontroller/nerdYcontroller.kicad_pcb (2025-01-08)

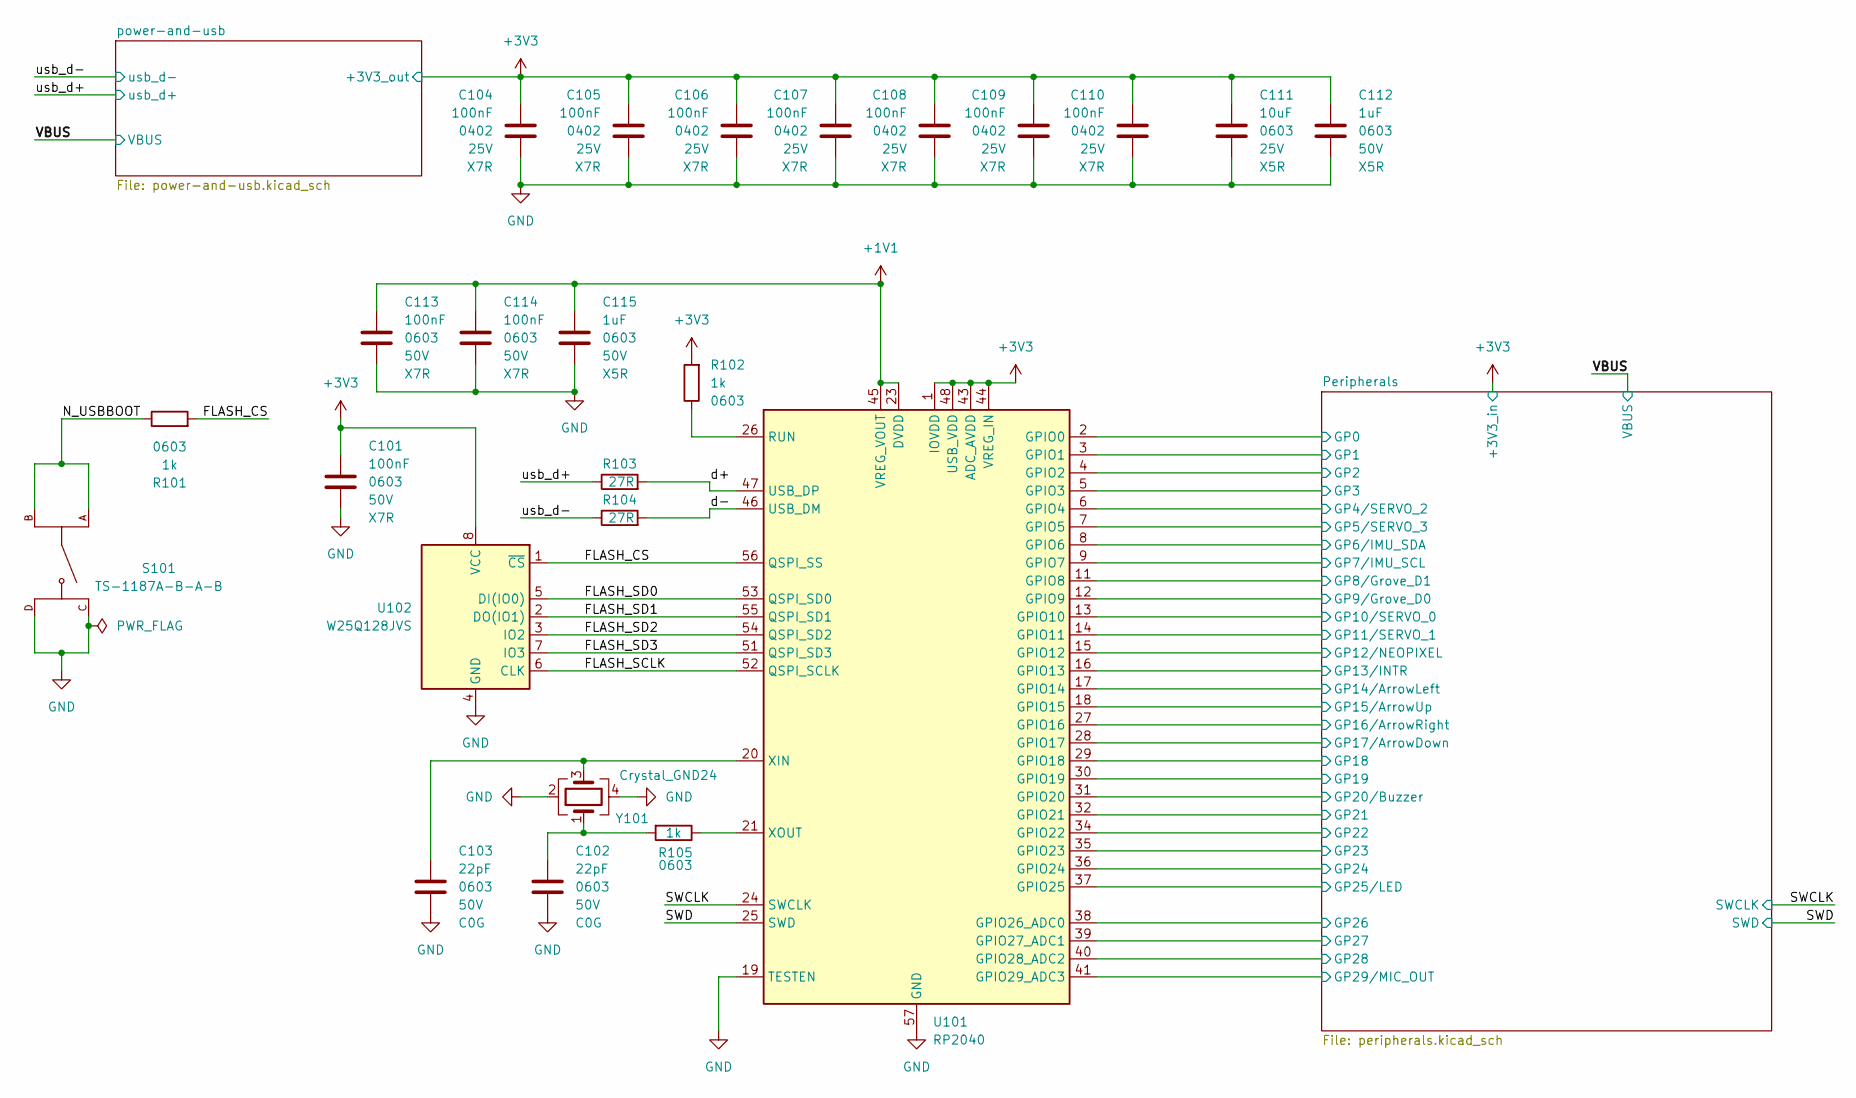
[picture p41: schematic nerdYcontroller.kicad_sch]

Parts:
C101, C113, C114: 100nF; C_0603_1608Metric; Voltage Rating 50V; LCSC Part # C14663
C102, C103: 22pF; C_0603_1608Metric; Voltage Rating 50V; LCSC Part # C1653
C104, C105, C106, C107, C108, C109, C110: 100nF; C_0402_1005Metric; Voltage Rating 25V; LCSC Part # C56392
C111: 10uF; C_0603_1608Metric; Voltage Rating 25V; LCSC Part # C96446
C112, C115: 1uF; C_0603_1608Metric; Voltage Rating 50V; LCSC Part # C15849
R101, R102, R105: 1k; R_0603_1608Metric; LCSC Part # C21190
R103, R104: 27R; R_0603_1608Metric; LCSC Part # C25190
S101: TS-1187A-B-A-B; SW_TS-1187A-B-A-B; LCSC Part # C318884
U101: RP2040; QFN-56-1EP_7x7mm_P0.4mm_EP3.2x3.2mm
U102: W25Q128JVS; SOIC-8_5.23x5.23mm_P1.27mm; LCSC Part # C97521
Y101: Crystal_GND24; Crystal_SMD_3225-4Pin_3.2x2.5mm; LCSC Part # C9002

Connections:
+1V1: C113.1, C114.1, C115.1, U101.23 (DVDD), U101.45 (VREG_VOUT), U101.50 (DVDD)
+3V3: C101.1, C104.2, C105.2, C106.2, C107.2, C108.2, C109.2, C110.2, C111.1, C112.1, R102.2, U101.1 (IOVDD), U101.10 (IOVDD), U101.22 (IOVDD), U101.33 (IOVDD), U101.42 (IOVDD), U101.43 (ADC_AVDD), U101.44 (VREG_IN), U101.48 (USB_VDD), U101.49 (IOVDD), U102.8 (VCC); also elsewhere on the board
/FLASH_CS: R101.2, U101.56 (QSPI_SS), U102.1 (~CS)
/FLASH_SCLK: U101.52 (QSPI_SCLK), U102.6 (CLK)
/FLASH_SD0: U101.53 (QSPI_SD0), U102.5 (DI(IO0))
/FLASH_SD1: U101.55 (QSPI_SD1), U102.2 (DO(IO1))
/FLASH_SD2: U101.54 (QSPI_SD2), U102.3 (IO2)
/FLASH_SD3: U101.51 (QSPI_SD3), U102.7 (IO3)
/N_USBBOOT: R101.1, S101.A, S101.B
/Peripherals/GP0: U101.2 (GPIO0); also elsewhere on the board
/Peripherals/GP1: U101.3 (GPIO1); also elsewhere on the board
/Peripherals/GP2: U101.4 (GPIO2); also elsewhere on the board
/Peripherals/GP3: U101.5 (GPIO3); also elsewhere on the board
/Peripherals/GP4/SERVO_2: U101.6 (GPIO4); also elsewhere on the board
/Peripherals/GP5/SERVO_3: U101.7 (GPIO5); also elsewhere on the board
/Peripherals/GP6/IMU_SDA: U101.8 (GPIO6); also elsewhere on the board
/Peripherals/GP7/IMU_SCL: U101.9 (GPIO7); also elsewhere on the board
/Peripherals/GP8/Grove_D1: U101.11 (GPIO8); also elsewhere on the board
/Peripherals/GP9/Grove_D0: U101.12 (GPIO9); also elsewhere on the board
/Peripherals/GP10/SERVO_0: U101.13 (GPIO10); also elsewhere on the board
/Peripherals/GP11/SERVO_1: U101.14 (GPIO11); also elsewhere on the board
/Peripherals/GP12/NEOPIXEL: U101.15 (GPIO12); also elsewhere on the board
/Peripherals/GP13/INTR: U101.16 (GPIO13); also elsewhere on the board
/Peripherals/GP14/ArrowLeft: U101.17 (GPIO14); also elsewhere on the board
/Peripherals/GP15/ArrowUp: U101.18 (GPIO15); also elsewhere on the board
/Peripherals/GP16/ArrowRight: U101.27 (GPIO16); also elsewhere on the board
/Peripherals/GP17/ArrowDown: U101.28 (GPIO17); also elsewhere on the board
/Peripherals/GP18: U101.29 (GPIO18); also elsewhere on the board
/Peripherals/GP19: U101.30 (GPIO19); also elsewhere on the board
/Peripherals/GP20/Buzzer: U101.31 (GPIO20); also elsewhere on the board
/Peripherals/GP21: U101.32 (GPIO21); also elsewhere on the board
/Peripherals/GP22: U101.34 (GPIO22); also elsewhere on the board
/Peripherals/GP23: U101.35 (GPIO23); also elsewhere on the board
/Peripherals/GP24: U101.36 (GPIO24); also elsewhere on the board
/Peripherals/GP25/LED: U101.37 (GPIO25); also elsewhere on the board
/Peripherals/GP26: U101.38 (GPIO26_ADC0); also elsewhere on the board
/Peripherals/GP27: U101.39 (GPIO27_ADC1); also elsewhere on the board
/Peripherals/GP28: U101.40 (GPIO28_ADC2); also elsewhere on the board
/Peripherals/GP29/MIC_OUT: U101.41 (GPIO29_ADC3); also elsewhere on the board
/SWCLK: U101.24 (SWCLK); also elsewhere on the board
/SWD: U101.25 (SWD); also elsewhere on the board
/d+: R103.2, U101.47 (USB_DP)
/d-: R104.2, U101.46 (USB_DM)
/usb_d+: R103.1; also elsewhere on the board
/usb_d-: R104.1; also elsewhere on the board
GND: C101.2, C102.2, C103.2, C104.1, C105.1, C106.1, C107.1, C108.1, C109.1, C110.1, C111.2, C112.2, C113.2, C114.2, C115.2, S101.C, S101.D, U101.19 (TESTEN), U101.57 (GND), U102.4 (GND), Y101.2, Y101.4; also elsewhere on the board
unnamed: C102.1, R105.2, Y101.1
unnamed: R102.1, U101.26 (RUN)
unnamed: C103.1, U101.20 (XIN), Y101.3
unnamed: R105.1, U101.21 (XOUT)

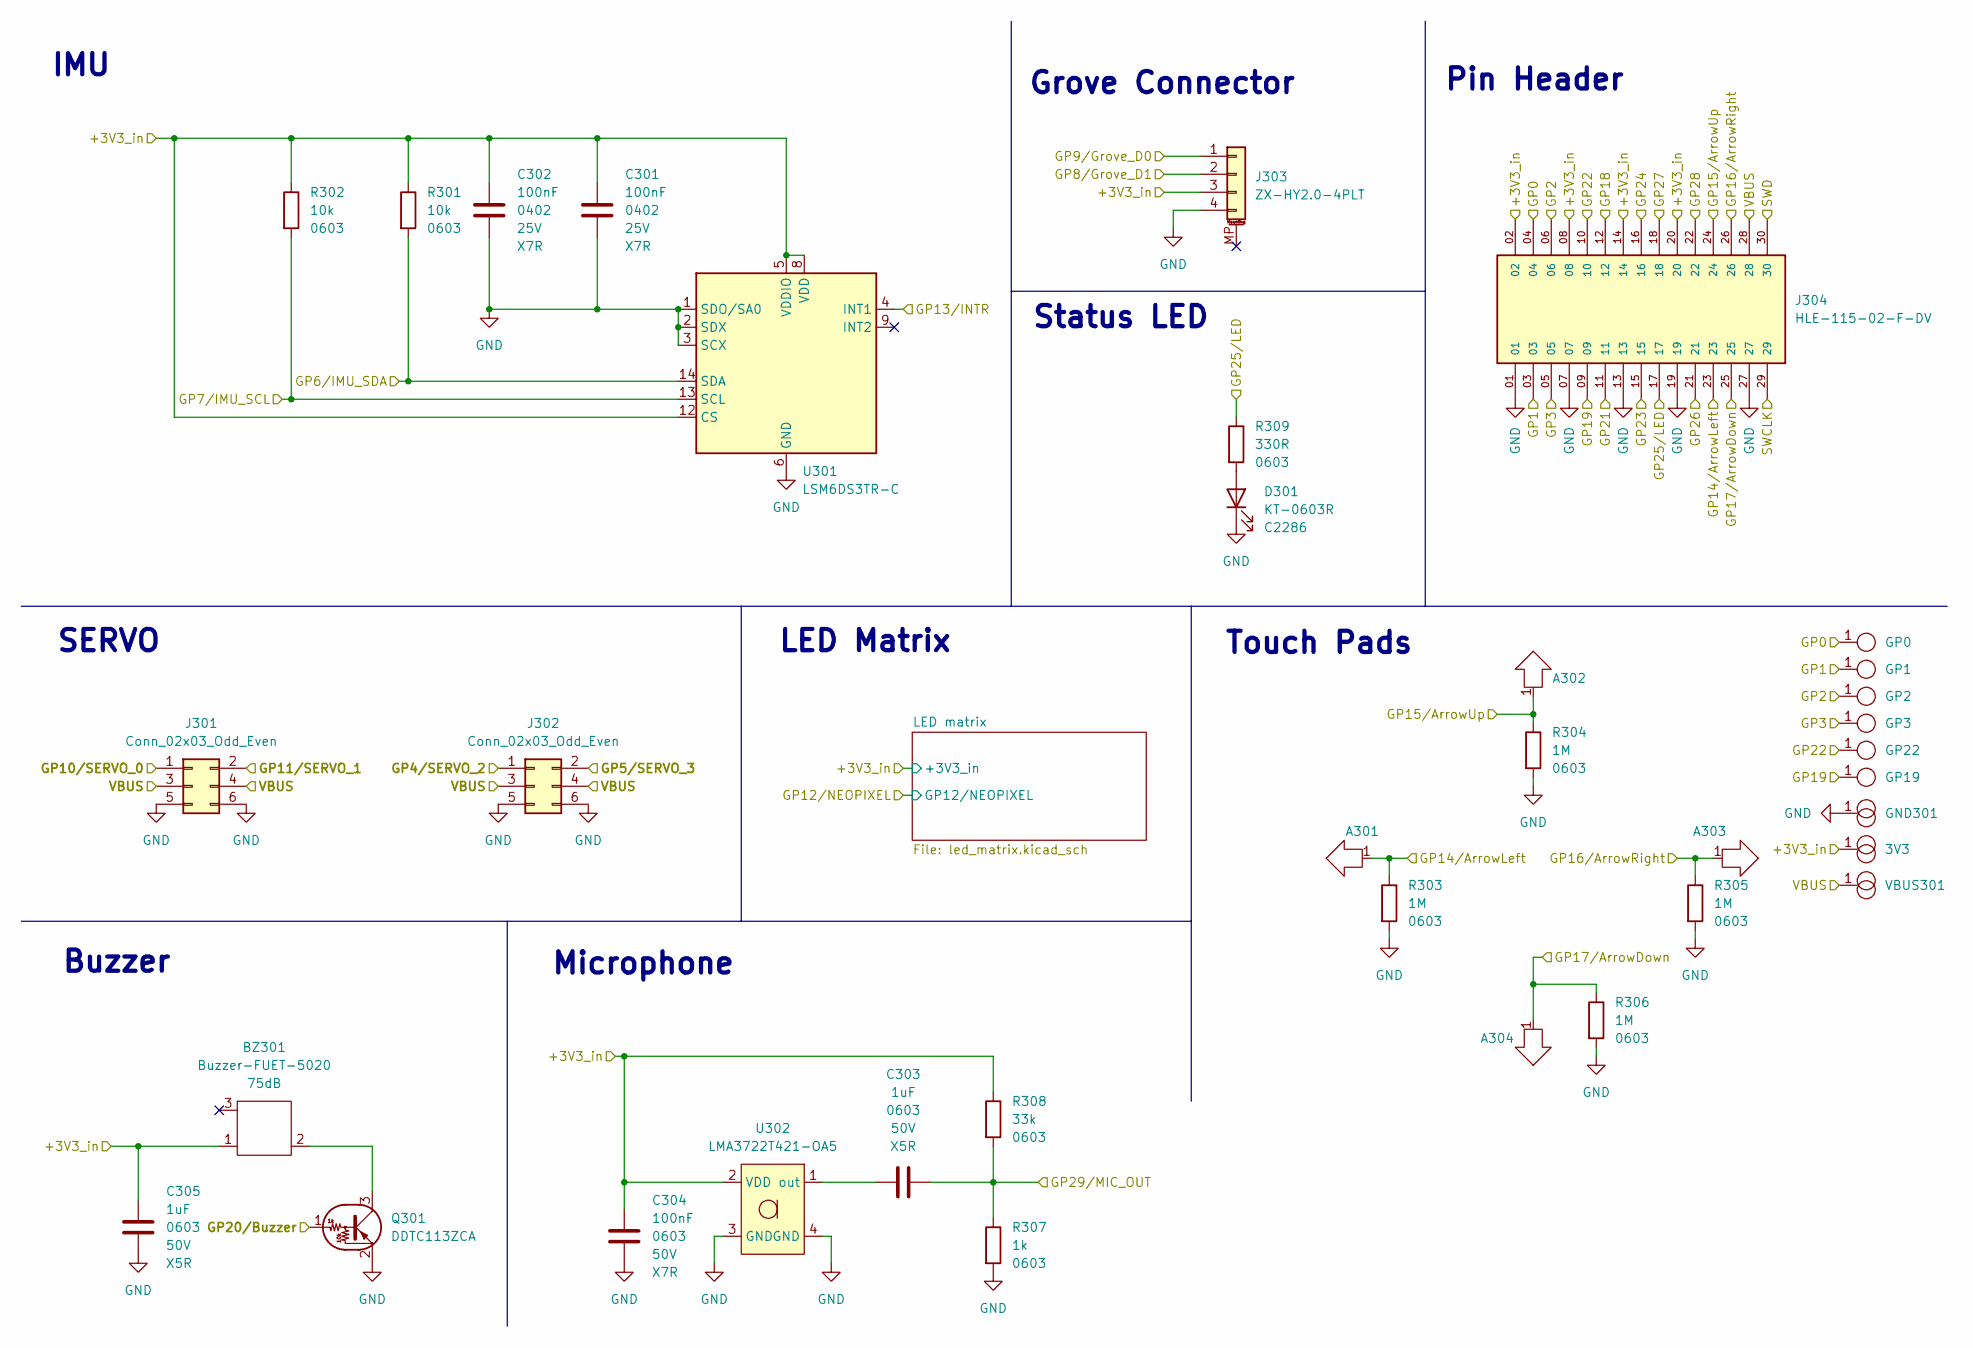
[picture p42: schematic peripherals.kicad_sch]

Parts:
3V3: kroko_doubleedge; DoubleEdge
A301, A302, A303, A304: arrow; Kroko_Arrow
BZ301: Buzzer-FUET-5020; FUET-5020; LCSC Part # C391029
C301, C302: 100nF; C_0402_1005Metric; Voltage Rating 25V; LCSC Part # C56392
C303, C305: 1uF; C_0603_1608Metric; Voltage Rating 50V; LCSC Part # C15849
C304: 100nF; C_0603_1608Metric; Voltage Rating 50V; LCSC Part # C14663
D301: KT-0603R; LED_0603_1608Metric; LCSC Part # C2286
GND301: kroko_doubleedge; DoubleEdge
GP0, GP1, GP2, GP3, GP19, GP22: kroko_edge; Edgeconnector
J301, J302: Conn_02x03_Odd_Even; PinHeader_2x03_P2.54mm_Vertical_SMD; LCSC Part # C192301
J303: ZX-HY2.0-4PLT; LCSC Part # C7429562
J304: HLE-115-02-F-DV; SAMTEC_HLE-115-02-F-DV
Q301: DDTC113ZCA; SOT-23; LCSC Part # C151437
R301, R302: 10k; R_0603_1608Metric; LCSC Part # C25804
R303, R304, R305, R306: 1M; R_0603_1608Metric; LCSC Part # C105578
R307: 1k; R_0603_1608Metric; LCSC Part # C21190
R308: 33k; R_0603_1608Metric; LCSC Part # C25593
R309: 330R; R_0603_1608Metric; LCSC Part # C22104
U301: LSM6DS3TR-C; LGA-14_3x2.5mm_P0.5mm_LayoutBorder3x4y; LCSC Part # C967633
U302: LMA3722T421-OA5; LCSC Part # C5373233
VBUS301: kroko_doubleedge; DoubleEdge

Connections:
+3V3: 3V3.1, BZ301.1 (+), C301.2, C302.2, C304.1, C305.1, J303.3, J304.02, J304.08, J304.14, J304.20, R301.1, R302.1, R308.1, U301.5 (VDDIO), U301.8 (VDD), U301.12 (CS), U302.2 (VDD); also elsewhere on the board
/Peripherals/GP0: GP0.1, J304.04; also elsewhere on the board
/Peripherals/GP1: GP1.1, J304.03; also elsewhere on the board
/Peripherals/GP2: GP2.1, J304.06; also elsewhere on the board
/Peripherals/GP3: GP3.1, J304.05; also elsewhere on the board
/Peripherals/GP4/SERVO_2: J302.1; also elsewhere on the board
/Peripherals/GP5/SERVO_3: J302.2; also elsewhere on the board
/Peripherals/GP6/IMU_SDA: R301.2, U301.14 (SDA); also elsewhere on the board
/Peripherals/GP7/IMU_SCL: R302.2, U301.13 (SCL); also elsewhere on the board
/Peripherals/GP8/Grove_D1: J303.2; also elsewhere on the board
/Peripherals/GP9/Grove_D0: J303.1; also elsewhere on the board
/Peripherals/GP10/SERVO_0: J301.1; also elsewhere on the board
/Peripherals/GP11/SERVO_1: J301.2; also elsewhere on the board
/Peripherals/GP13/INTR: U301.4 (INT1); also elsewhere on the board
/Peripherals/GP14/ArrowLeft: A301.1, J304.23, R303.1; also elsewhere on the board
/Peripherals/GP15/ArrowUp: A302.1, J304.24, R304.1; also elsewhere on the board
/Peripherals/GP16/ArrowRight: A303.1, J304.26, R305.1; also elsewhere on the board
/Peripherals/GP17/ArrowDown: A304.1, J304.25, R306.1; also elsewhere on the board
/Peripherals/GP18: J304.12; also elsewhere on the board
/Peripherals/GP19: GP19.1, J304.09; also elsewhere on the board
/Peripherals/GP20/Buzzer: Q301.1 (B); also elsewhere on the board
/Peripherals/GP21: J304.11; also elsewhere on the board
/Peripherals/GP22: GP22.1, J304.10; also elsewhere on the board
/Peripherals/GP23: J304.15; also elsewhere on the board
/Peripherals/GP24: J304.16; also elsewhere on the board
/Peripherals/GP25/LED: J304.17, R309.1; also elsewhere on the board
/Peripherals/GP26: J304.21; also elsewhere on the board
/Peripherals/GP27: J304.18; also elsewhere on the board
/Peripherals/GP28: J304.22; also elsewhere on the board
/Peripherals/GP29/MIC_OUT: C303.2, R307.1, R308.2; also elsewhere on the board
/SWCLK: J304.29; also elsewhere on the board
/SWD: J304.30; also elsewhere on the board
/VBUS: J301.3, J301.4, J302.3, J302.4, J304.28, VBUS301.1; also elsewhere on the board
GND: C301.1, C302.1, C304.2, C305.2, D301.1 (K), GND301.1, J301.5, J301.6, J302.5, J302.6, J303.4, J304.01, J304.07, J304.13, J304.19, J304.27, Q301.2 (E), R303.2, R304.2, R305.2, R306.2, R307.2, U301.1 (SDO/SA0), U301.2 (SDX), U301.3 (SCX), U301.6 (GND), U301.7 (GND), U302.3 (GND), U302.4 (GND); also elsewhere on the board
unnamed: BZ301.2 (-), Q301.3 (C)
unnamed: D301.2 (A), R309.2
unnamed: C303.1, U302.1 (out)

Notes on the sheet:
Pin Header
Buzzer
Grove Connector
SERVO
LED Matrix
Microphone
Status LED
IMU
Touch Pads

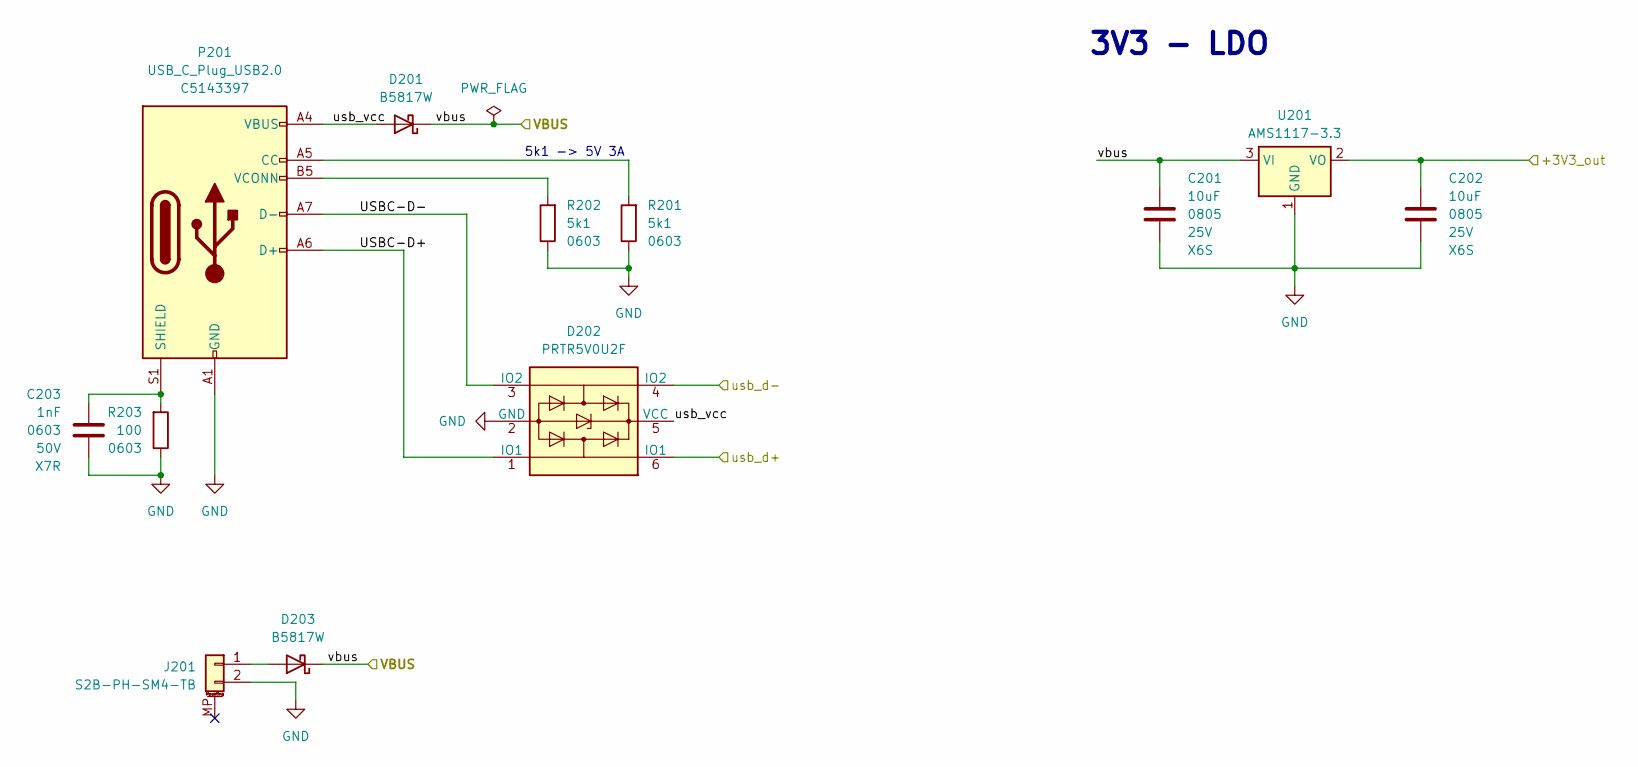
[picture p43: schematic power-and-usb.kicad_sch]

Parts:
C201, C202: 10uF; C_0805_2012Metric; Voltage Rating 25V; LCSC Part # C710989
C203: 1nF; C_0603_1608Metric; Voltage Rating 50V; LCSC Part # C1588
D201, D203: B5817W; D_SOD-123; LCSC Part # C2909923
D202: PRTR5V0U2F; WSON-6_1.5x1.5mm_P0.5mm; LCSC Part # C2937001
J201: S2B-PH-SM4-TB; JST_PH_S2B-PH-SM4-TB_1x02-1MP_P2.00mm_Horizontal; LCSC Part # C295747
P201: USB_C_Plug_USB2.0; USB_C_Receptacle_GCT_USB4110; LCSC Part # C5143397
R201, R202: 5k1; R_0603_1608Metric; LCSC Part # C23186
R203: 100; R_0603_1608Metric; LCSC Part # C22775
U201: AMS1117-3.3; SOT-223-3_TabPin2; LCSC Part # C6186

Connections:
+3V3: C202.1, U201.2 (VO); also elsewhere on the board
/VBUS: C201.1, D201.1 (K), D203.1 (K), U201.3 (VI); also elsewhere on the board
/power-and-usb/USBC-D+: D202.1 (IO1), P201.A6 (D+)
/power-and-usb/USBC-D-: D202.3 (IO2), P201.A7 (D-)
/power-and-usb/usb_vcc: D201.2 (A), D202.5 (VCC), P201.A4 (VBUS), P201.A9 (VBUS), P201.B4 (VBUS), P201.B9 (VBUS)
/usb_d+: D202.6 (IO1); also elsewhere on the board
/usb_d-: D202.4 (IO2); also elsewhere on the board
GND: C201.2, C202.2, C203.2, D202.2 (GND), J201.2, P201.A1 (GND), P201.A12 (GND), P201.B1 (GND), P201.B12 (GND), R201.1, R202.1, R203.1, U201.1 (GND); also elsewhere on the board
unnamed: D203.2 (A), J201.1
unnamed: P201.A5 (CC), R201.2
unnamed: C203.1, P201.S1 (SHIELD), R203.2
unnamed: P201.B5 (VCONN), R202.2

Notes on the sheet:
5k1 -> 5V 3A
3V3 - LDO

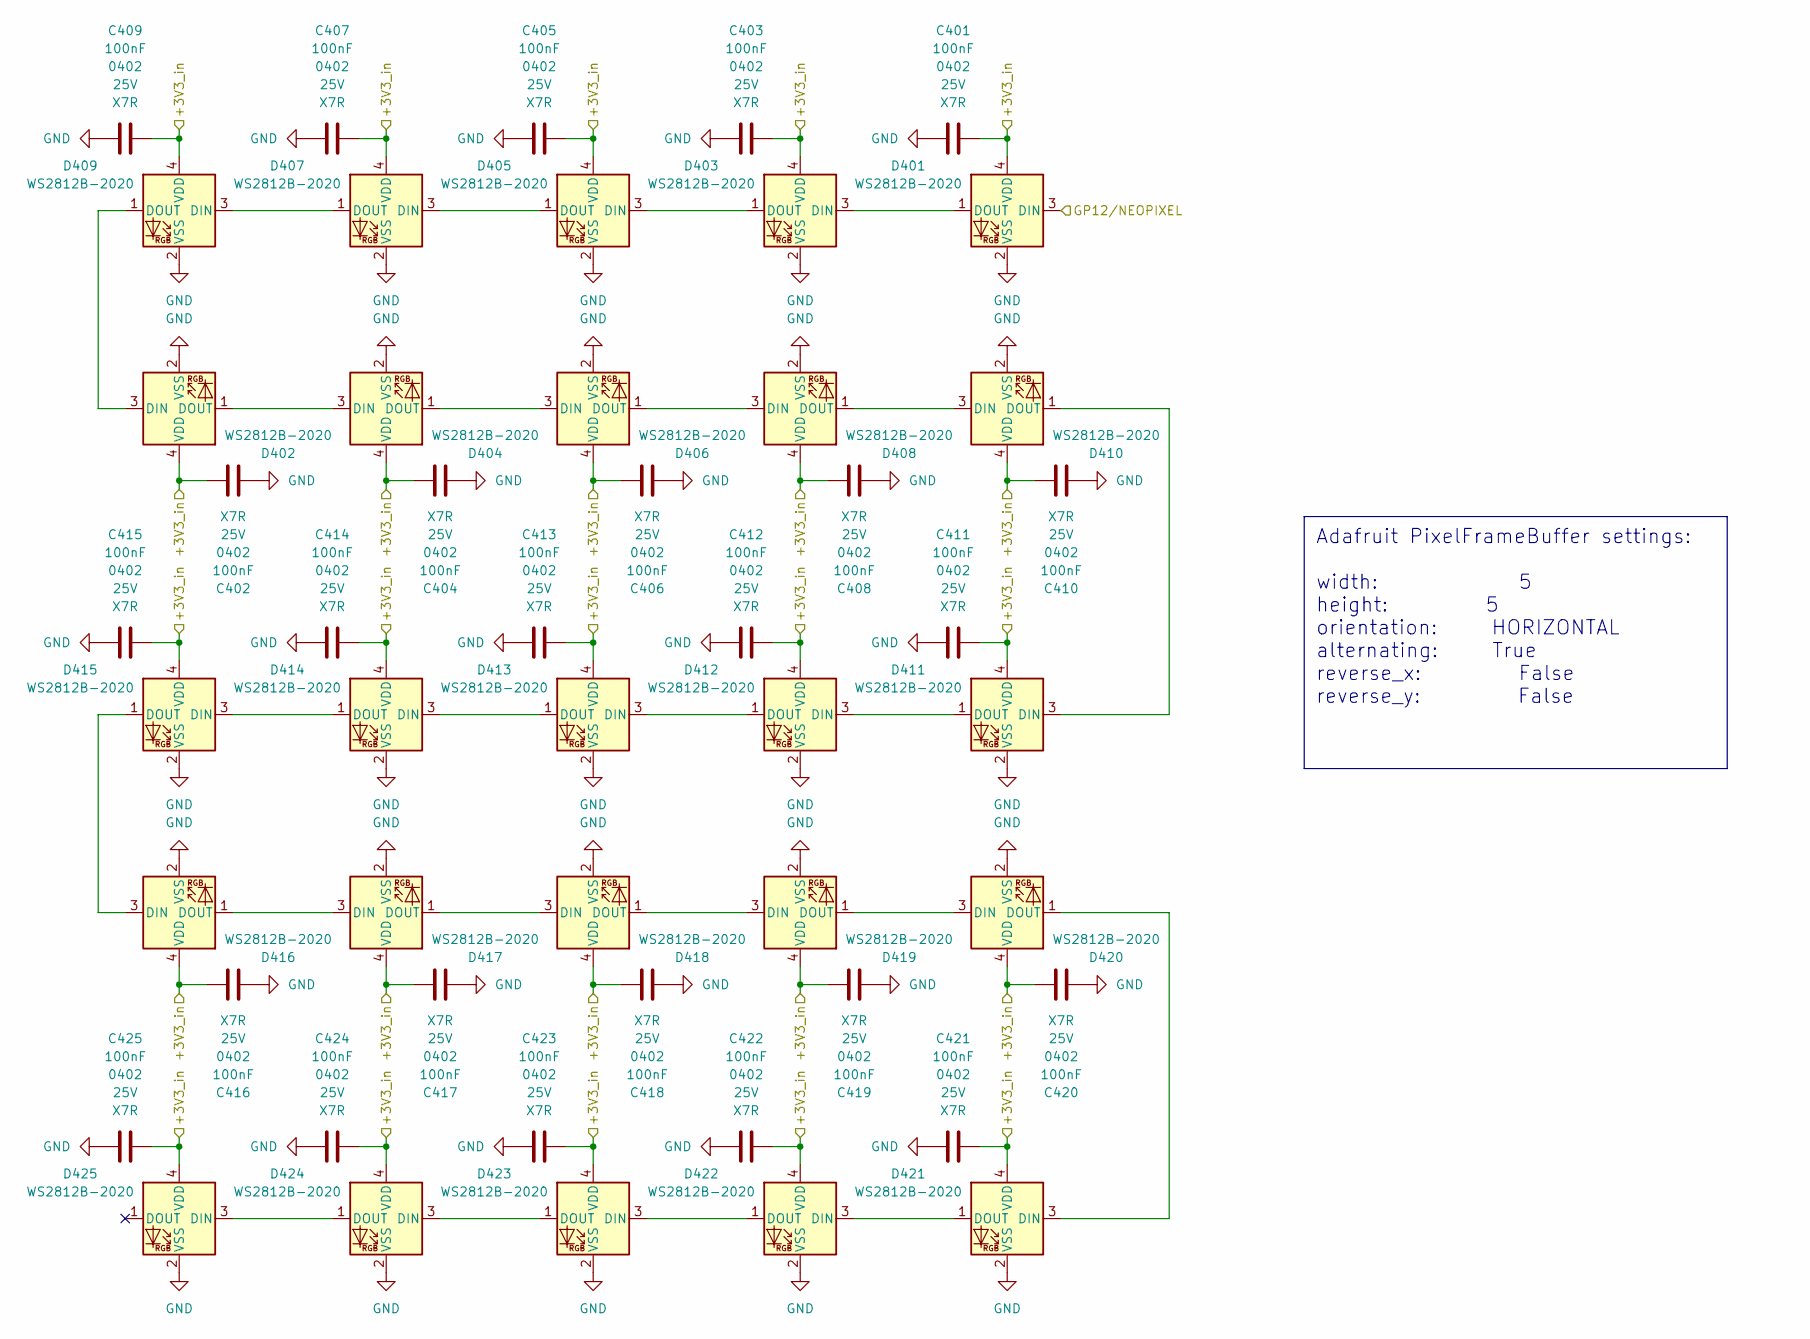
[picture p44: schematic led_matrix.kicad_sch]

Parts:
C401, C402, C403, C404, C405, C406, C407, C408, C409, C410, C411, C412, C413, C414, C415, C416, C417, C418, C419, C420, C421, C422, C423, C424, C425: 100nF; C_0402_1005Metric; Voltage Rating 25V; LCSC Part # C56392
D401, D402, D403, D404, D405, D406, D407, D408, D409, D410, D411, D412, D413, D414, D415, D416, D417, D418, D419, D420, D421, D422, D423, D424, D425: WS2812B-2020; LED_WS2812B-2020_PLCC4_2.0x2.0mm; LCSC Part # C965555

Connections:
+3V3: C401.1, C402.1, C403.1, C404.1, C405.1, C406.1, C407.1, C408.1, C409.1, C410.1, C411.1, C412.1, C413.1, C414.1, C415.1, C416.1, C417.1, C418.1, C419.1, C420.1, C421.1, C422.1, C423.1, C424.1, C425.1, D401.4 (VDD), D402.4 (VDD), D403.4 (VDD), D404.4 (VDD), D405.4 (VDD), D406.4 (VDD), D407.4 (VDD), D408.4 (VDD), D409.4 (VDD), D410.4 (VDD), D411.4 (VDD), D412.4 (VDD), D413.4 (VDD), D414.4 (VDD), D415.4 (VDD), D416.4 (VDD), D417.4 (VDD), D418.4 (VDD), D419.4 (VDD), D420.4 (VDD), D421.4 (VDD), D422.4 (VDD), D423.4 (VDD), D424.4 (VDD), D425.4 (VDD); also elsewhere on the board
/Peripherals/GP12/NEOPIXEL: D401.3 (DIN); also elsewhere on the board
GND: C401.2, C402.2, C403.2, C404.2, C405.2, C406.2, C407.2, C408.2, C409.2, C410.2, C411.2, C412.2, C413.2, C414.2, C415.2, C416.2, C417.2, C418.2, C419.2, C420.2, C421.2, C422.2, C423.2, C424.2, C425.2, D401.2 (VSS), D402.2 (VSS), D403.2 (VSS), D404.2 (VSS), D405.2 (VSS), D406.2 (VSS), D407.2 (VSS), D408.2 (VSS), D409.2 (VSS), D410.2 (VSS), D411.2 (VSS), D412.2 (VSS), D413.2 (VSS), D414.2 (VSS), D415.2 (VSS), D416.2 (VSS), D417.2 (VSS), D418.2 (VSS), D419.2 (VSS), D420.2 (VSS), D421.2 (VSS), D422.2 (VSS), D423.2 (VSS), D424.2 (VSS), D425.2 (VSS); also elsewhere on the board
unnamed: D401.1 (DOUT), D403.3 (DIN)
unnamed: D402.3 (DIN), D409.1 (DOUT)
unnamed: D402.1 (DOUT), D404.3 (DIN)
unnamed: D403.1 (DOUT), D405.3 (DIN)
unnamed: D404.1 (DOUT), D406.3 (DIN)
unnamed: D405.1 (DOUT), D407.3 (DIN)
unnamed: D406.1 (DOUT), D408.3 (DIN)
unnamed: D407.1 (DOUT), D409.3 (DIN)
unnamed: D408.1 (DOUT), D410.3 (DIN)
unnamed: D410.1 (DOUT), D411.3 (DIN)
unnamed: D411.1 (DOUT), D412.3 (DIN)
unnamed: D412.1 (DOUT), D413.3 (DIN)
unnamed: D413.1 (DOUT), D414.3 (DIN)
unnamed: D414.1 (DOUT), D415.3 (DIN)
unnamed: D415.1 (DOUT), D416.3 (DIN)
unnamed: D416.1 (DOUT), D417.3 (DIN)
unnamed: D417.1 (DOUT), D418.3 (DIN)
unnamed: D418.1 (DOUT), D419.3 (DIN)
unnamed: D419.1 (DOUT), D420.3 (DIN)
unnamed: D420.1 (DOUT), D421.3 (DIN)
unnamed: D421.1 (DOUT), D422.3 (DIN)
unnamed: D422.1 (DOUT), D423.3 (DIN)
unnamed: D423.1 (DOUT), D424.3 (DIN)
unnamed: D424.1 (DOUT), D425.3 (DIN)

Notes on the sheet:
Adafruit PixelFrameBuffer settings: width: 5 height: 5 orientation: HORIZONTAL alternating: True reverse_x: False reverse_y: False

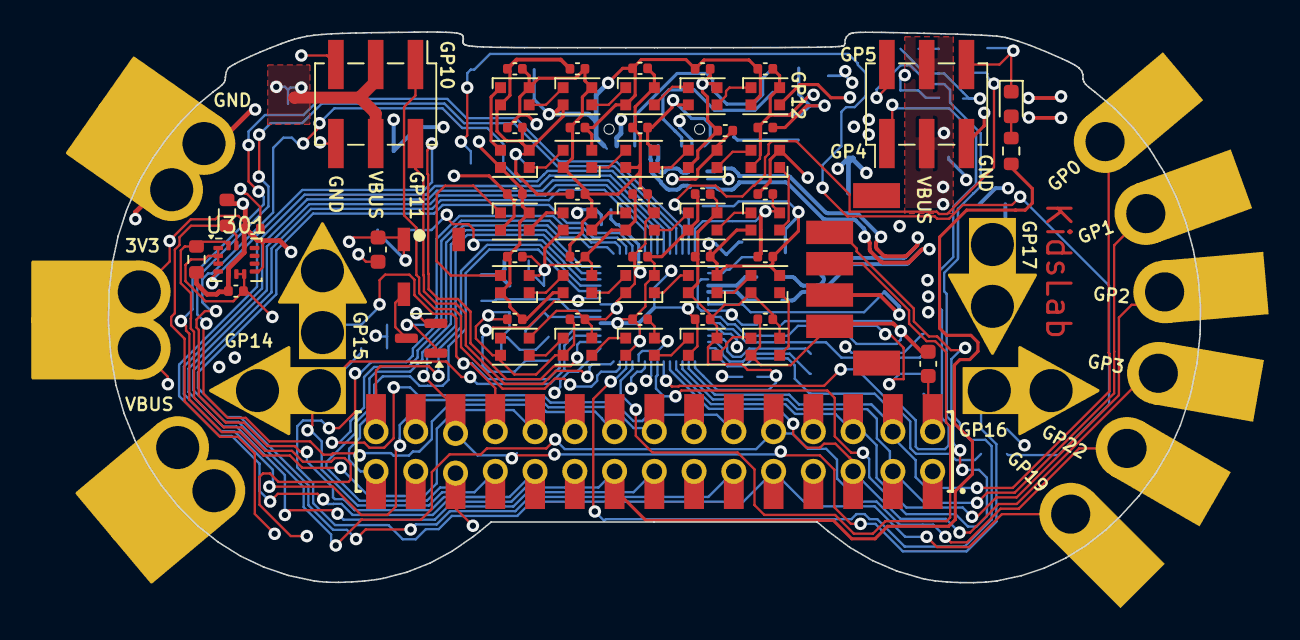
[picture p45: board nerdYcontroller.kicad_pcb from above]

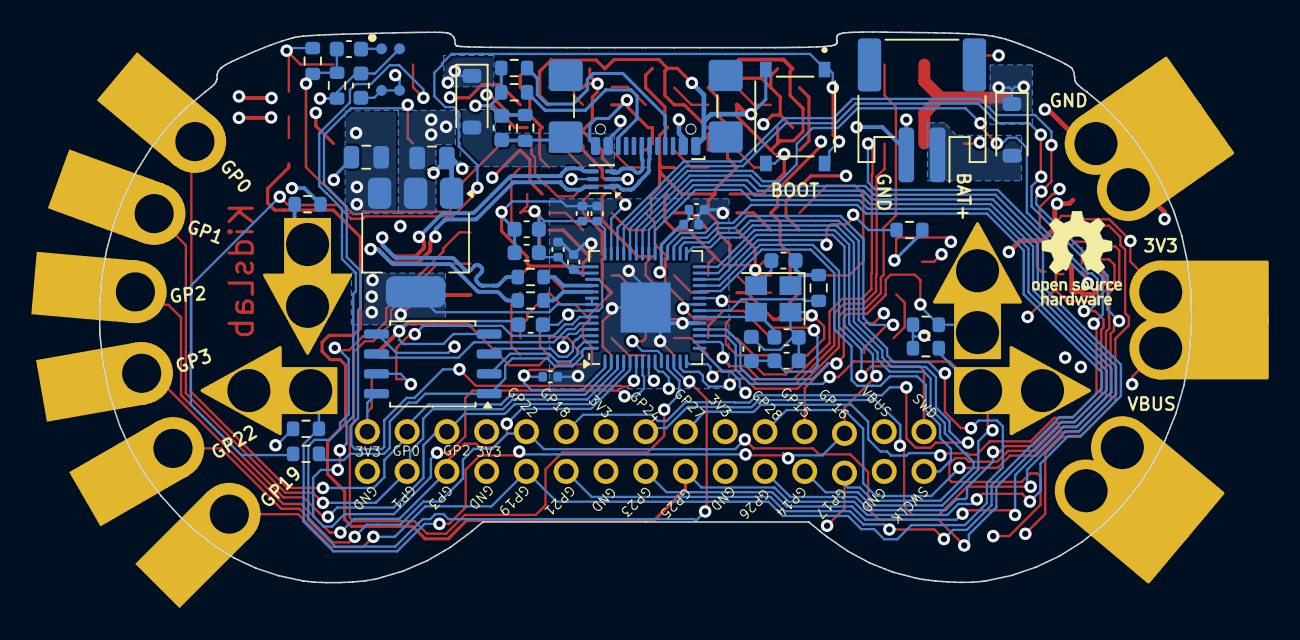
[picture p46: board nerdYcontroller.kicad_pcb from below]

Board: 4 copper layers, 69.8 x 35.2 mm, 123 parts (44 on the bottom side), 85 nets.

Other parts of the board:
outline: Gamecontroller Outline

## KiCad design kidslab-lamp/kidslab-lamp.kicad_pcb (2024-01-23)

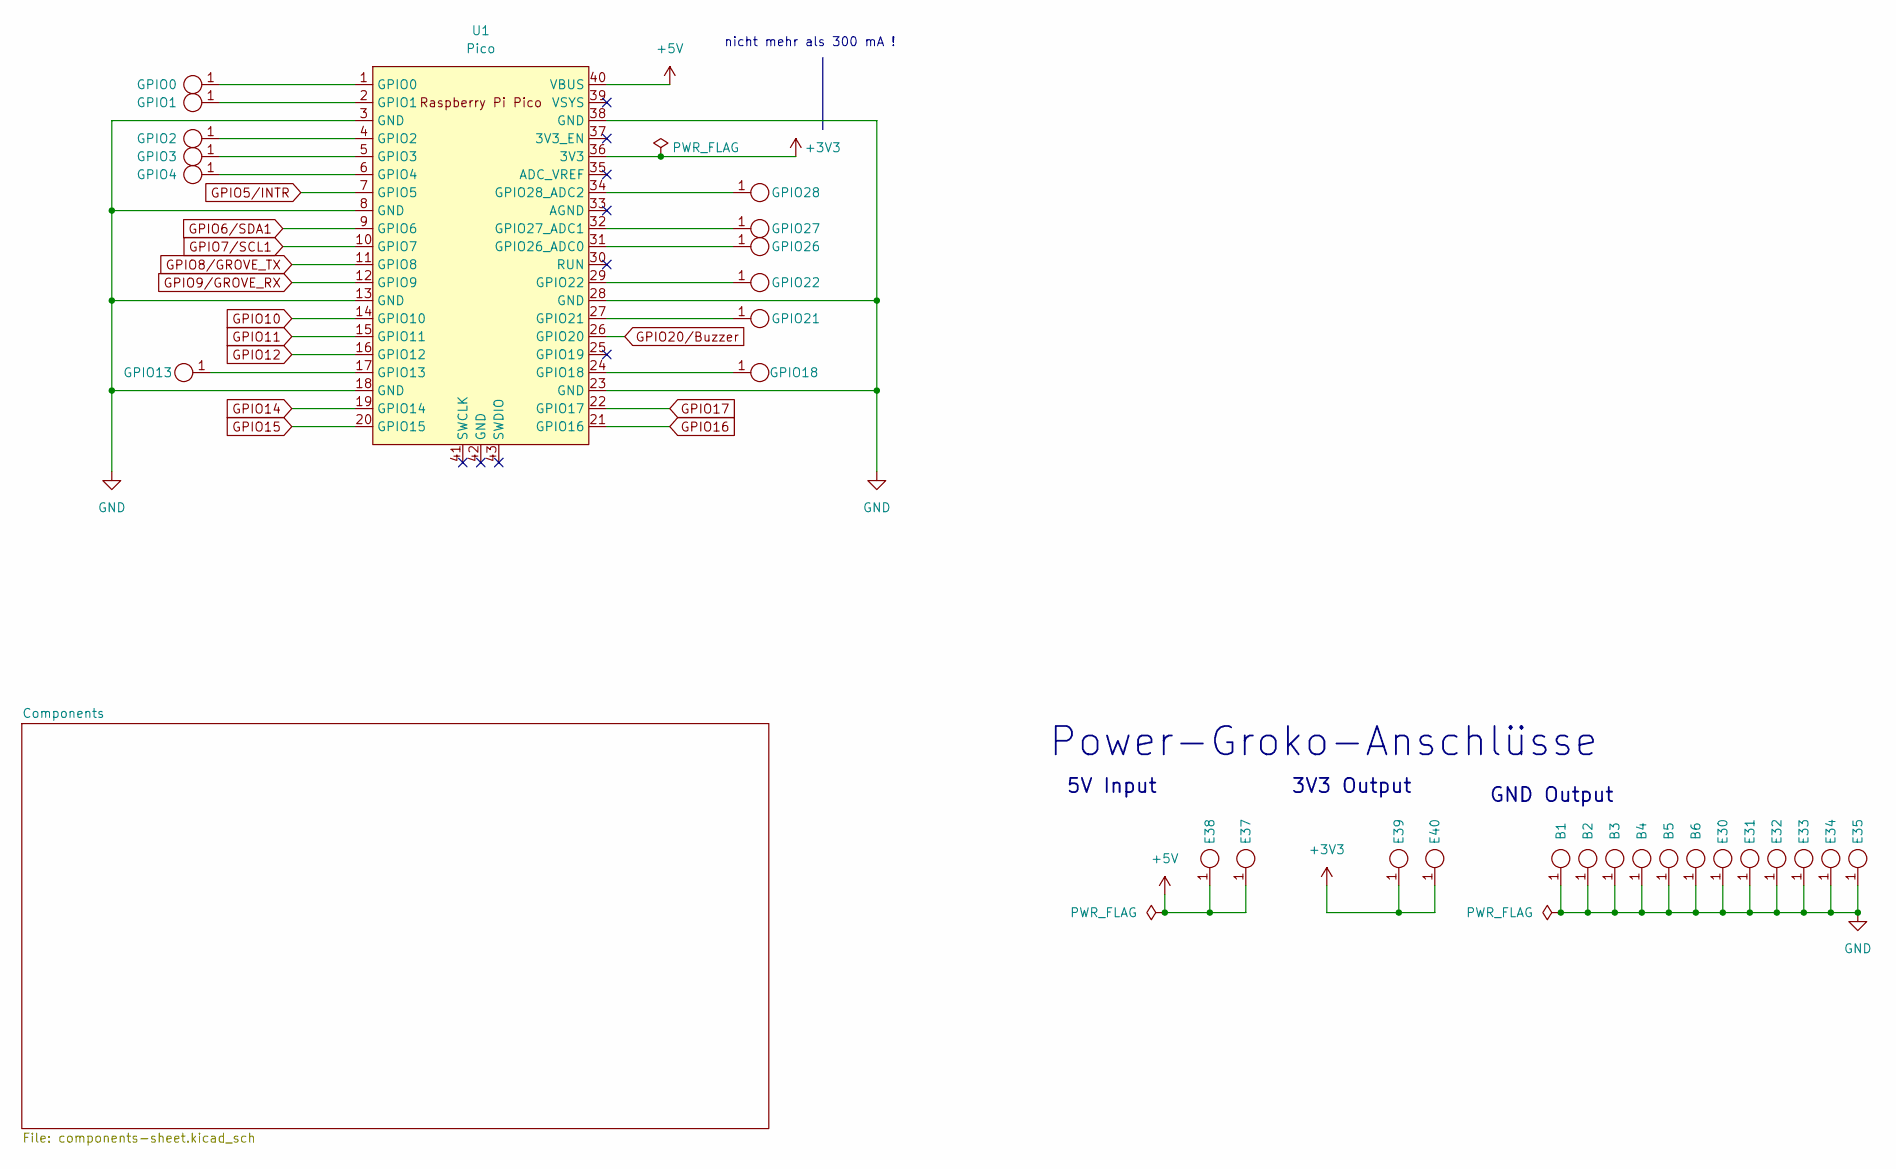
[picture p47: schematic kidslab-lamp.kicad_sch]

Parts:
B1, B2, B3, B4, B5, B6: kroko_board; KrokoConnector
E30, E31, E32, E33, E34, E35, E37, E38, E39, E40: kroko_edge; Edgeconnector
GPIO0, GPIO1, GPIO2, GPIO3, GPIO4, GPIO21, GPIO22, GPIO26, GPIO27, GPIO28: kroko_edge; Edgeconnector
GPIO13, GPIO18: kroko_board; KrokoConnector
U1: Pico; RPi_Pico_SMD_TH

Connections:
+3V3: E39.1, E40.1, U1.36 (3V3); also elsewhere on the board
+5V: E37.1, E38.1, U1.40 (VBUS); also elsewhere on the board
GND: B1.1, B2.1, B3.1, B4.1, B5.1, B6.1, E30.1, E31.1, E32.1, E33.1, E34.1, E35.1, U1.3 (GND), U1.8 (GND), U1.13 (GND), U1.18 (GND), U1.23 (GND), U1.28 (GND), U1.38 (GND); also elsewhere on the board
GPIO5/INTR: U1.7 (GPIO5); also elsewhere on the board
GPIO6/SDA1: U1.9 (GPIO6); also elsewhere on the board
GPIO7/SCL1: U1.10 (GPIO7); also elsewhere on the board
GPIO8/GROVE_TX: U1.11 (GPIO8); also elsewhere on the board
GPIO9/GROVE_RX: U1.12 (GPIO9); also elsewhere on the board
GPIO10: U1.14 (GPIO10); also elsewhere on the board
GPIO11: U1.15 (GPIO11); also elsewhere on the board
GPIO12: U1.16 (GPIO12); also elsewhere on the board
GPIO14: U1.19 (GPIO14); also elsewhere on the board
GPIO15: U1.20 (GPIO15); also elsewhere on the board
GPIO16: U1.21 (GPIO16); also elsewhere on the board
GPIO17: U1.22 (GPIO17); also elsewhere on the board
GPIO20/Buzzer: U1.26 (GPIO20); also elsewhere on the board
unnamed: GPIO0.1, U1.1 (GPIO0)
unnamed: GPIO1.1, U1.2 (GPIO1)
unnamed: GPIO2.1, U1.4 (GPIO2)
unnamed: GPIO3.1, U1.5 (GPIO3)
unnamed: GPIO4.1, U1.6 (GPIO4)
unnamed: GPIO13.1, U1.17 (GPIO13)
unnamed: GPIO18.1, U1.24 (GPIO18)
unnamed: GPIO21.1, U1.27 (GPIO21)
unnamed: GPIO22.1, U1.29 (GPIO22)
unnamed: GPIO26.1, U1.31 (GPIO26_ADC0)
unnamed: GPIO27.1, U1.32 (GPIO27_ADC1)
unnamed: GPIO28.1, U1.34 (GPIO28_ADC2)

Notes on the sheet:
nicht mehr als 300 mA !
GND Output
3V3 Output
Power-Groko-Anschlüsse
5V Input

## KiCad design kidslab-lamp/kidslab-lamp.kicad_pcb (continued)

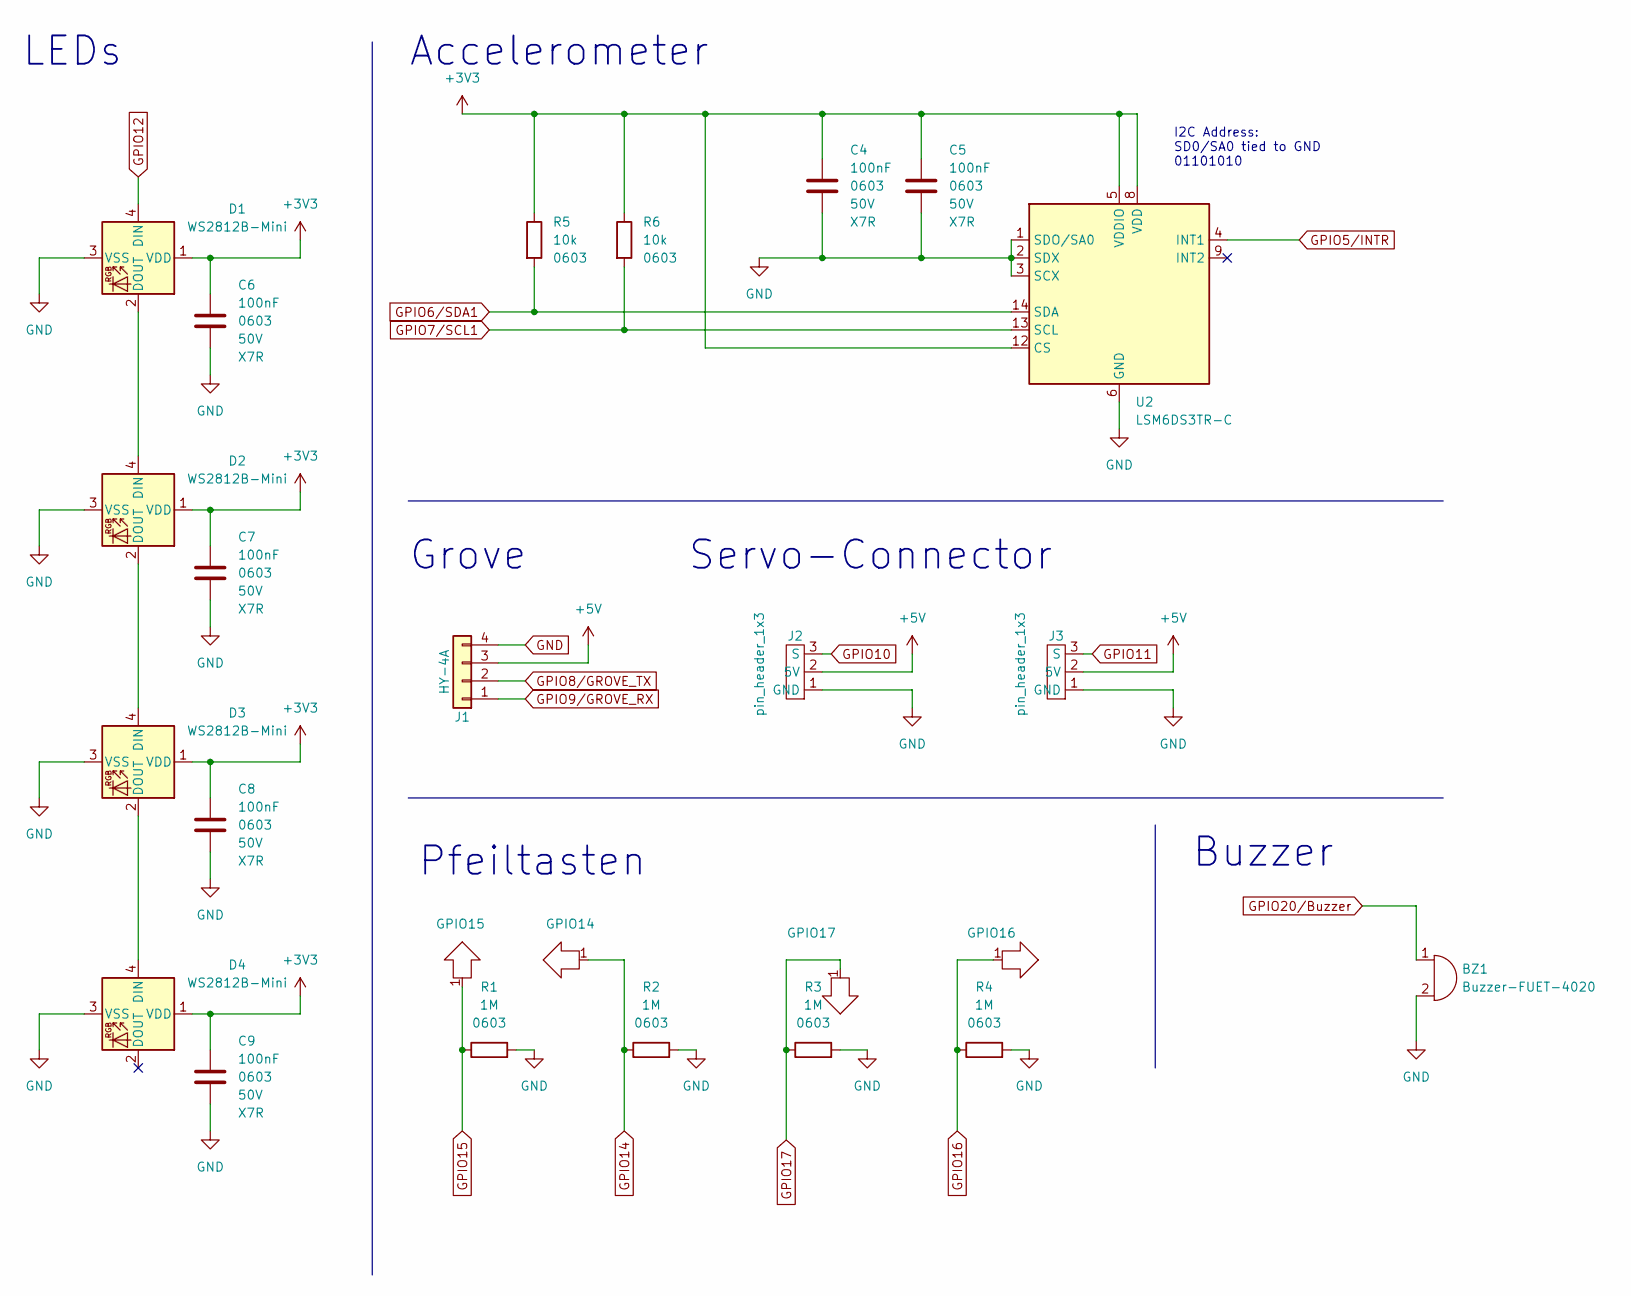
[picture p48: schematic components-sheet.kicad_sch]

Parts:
BZ1: Buzzer-FUET-4020; LCSC Part # C391027
C4, C5, C6, C7, C8, C9: 100nF; C_0603_1608Metric; Voltage Rating 50V; LCSC Part # C14663
D1, D2, D3, D4: WS2812B-Mini; LCSC Part # C527089
GPIO14, GPIO15, GPIO16, GPIO17: arrow; Kroko_Arrow
J1: HY-4A; HY-4A-THT; LCSC Part # C146064
J2, J3: pin_header_1x3; PinHeader_1x03_P2.54mm_Vertical
R1, R2, R3, R4: 1M; R_0603_1608Metric; LCSC Part # C105578
R5, R6: 10k; R_0603_1608Metric; LCSC Part # C25804
U2: LSM6DS3TR-C; LGA-14_3x2.5mm_P0.5mm_LayoutBorder3x4y; LCSC Part # C967633

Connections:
+3V3: C4.1, C5.1, C6.1, C7.1, C8.1, C9.1, D1.1 (VDD), D2.1 (VDD), D3.1 (VDD), D4.1 (VDD), R5.1, R6.1, U2.5 (VDDIO), U2.8 (VDD), U2.12 (CS); also elsewhere on the board
+5V: J1.3, J2.2 (5V), J3.2 (5V); also elsewhere on the board
GND: BZ1.2 (+), C4.2, C5.2, C6.2, C7.2, C8.2, C9.2, D1.3 (VSS), D2.3 (VSS), D3.3 (VSS), D4.3 (VSS), J1.4, J2.1 (GND), J3.1 (GND), R1.2, R2.2, R3.2, R4.2, U2.1 (SDO/SA0), U2.2 (SDX), U2.3 (SCX), U2.6 (GND), U2.7 (GND); also elsewhere on the board
GPIO5/INTR: U2.4 (INT1); also elsewhere on the board
GPIO6/SDA1: R5.2, U2.14 (SDA); also elsewhere on the board
GPIO7/SCL1: R6.2, U2.13 (SCL); also elsewhere on the board
GPIO8/GROVE_TX: J1.2; also elsewhere on the board
GPIO9/GROVE_RX: J1.1; also elsewhere on the board
GPIO10: J2.3 (S); also elsewhere on the board
GPIO11: J3.3 (S); also elsewhere on the board
GPIO12: D1.4 (DIN); also elsewhere on the board
GPIO14: GPIO14.1, R2.1; also elsewhere on the board
GPIO15: GPIO15.1, R1.1; also elsewhere on the board
GPIO16: GPIO16.1, R4.1; also elsewhere on the board
GPIO17: GPIO17.1, R3.1; also elsewhere on the board
GPIO20/Buzzer: BZ1.1 (-); also elsewhere on the board
unnamed: D1.2 (DOUT), D2.4 (DIN)
unnamed: D2.2 (DOUT), D3.4 (DIN)
unnamed: D3.2 (DOUT), D4.4 (DIN)

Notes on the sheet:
Pfeiltasten
Buzzer
I2C Address: SD0/SA0 tied to GND 01101010
Accelerometer
Grove
Servo-Connector
LEDs

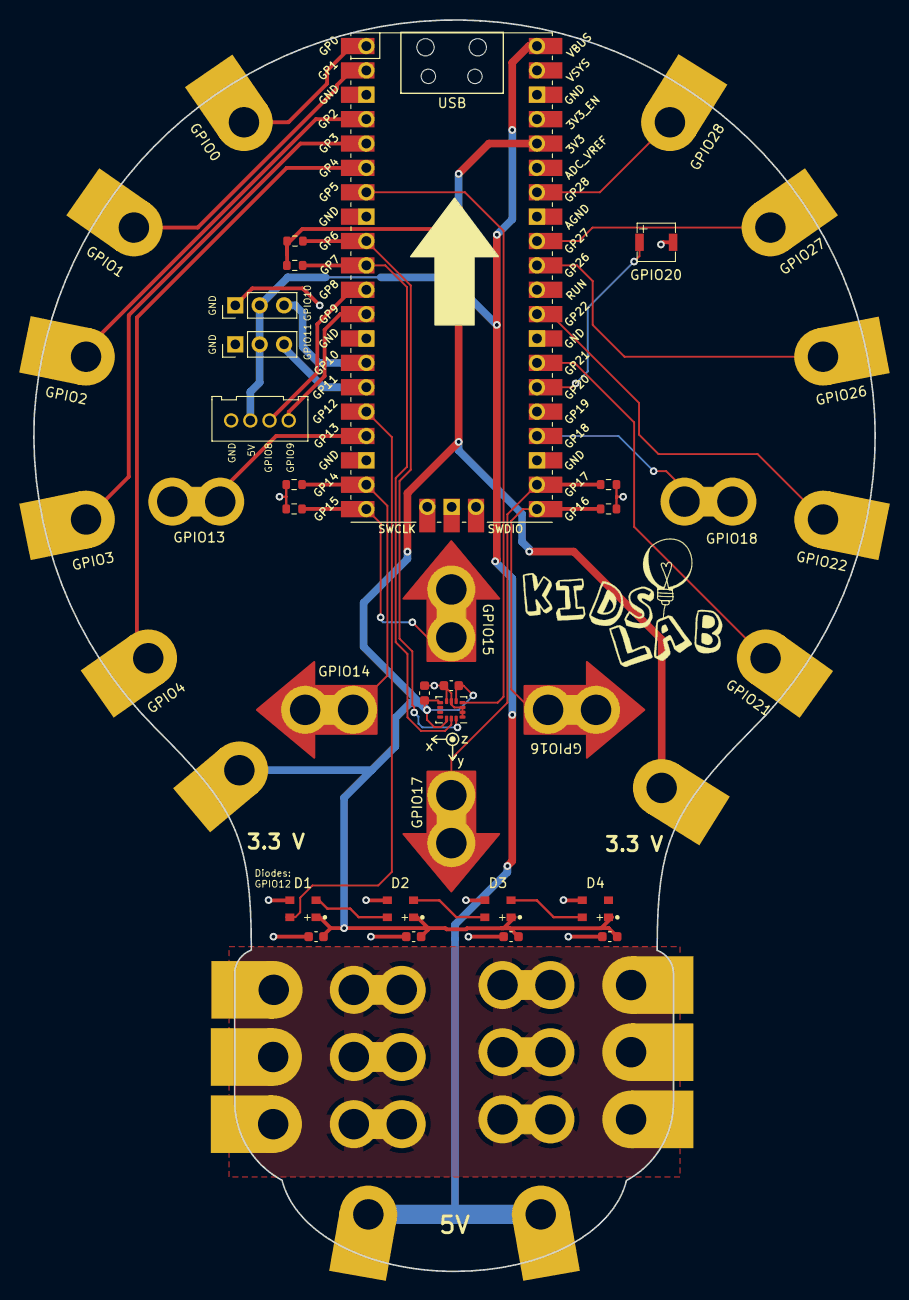
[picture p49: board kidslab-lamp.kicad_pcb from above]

Board: 2 copper layers, 87.7 x 130.4 mm, 54 parts (0 on the bottom side), 31 nets.

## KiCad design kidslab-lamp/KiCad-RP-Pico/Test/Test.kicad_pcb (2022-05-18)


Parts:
J1, J2: Conn_01x20; PinSocket_1x20_P1.00mm_Vertical
J3: Conn_01x03; PinSocket_1x03_P1.00mm_Vertical
U1: Pico; RPi_Pico_SMD_TH

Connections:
GND: J1.3, J1.8, J1.13, J1.18, J2.3, J2.13, J2.18, J3.2, U1.3 (GND), U1.8 (GND), U1.13 (GND), U1.18 (GND), U1.23 (GND), U1.28 (GND), U1.38 (GND), U1.42 (GND)
unnamed: J1.1, U1.1 (GPIO0)
unnamed: J1.2, U1.2 (GPIO1)
unnamed: J1.4, U1.4 (GPIO2)
unnamed: J1.5, U1.5 (GPIO3)
unnamed: J1.6, U1.6 (GPIO4)
unnamed: J1.7, U1.7 (GPIO5)
unnamed: J1.9, U1.9 (GPIO6)
unnamed: J1.10, U1.10 (GPIO7)
unnamed: J1.11, U1.11 (GPIO8)
unnamed: J1.12, U1.12 (GPIO9)
unnamed: J1.14, U1.14 (GPIO10)
unnamed: J1.15, U1.15 (GPIO11)
unnamed: J1.16, U1.16 (GPIO12)
unnamed: J1.17, U1.17 (GPIO13)
unnamed: J1.19, U1.19 (GPIO14)
unnamed: J1.20, U1.20 (GPIO15)
unnamed: J2.1, U1.40 (VBUS)
unnamed: J2.2, U1.39 (VSYS)
unnamed: J2.4, U1.37 (3V3_EN)
unnamed: J2.5, U1.36 (3V3)
unnamed: J2.6, U1.35 (ADC_VREF)
unnamed: J2.7, U1.34 (GPIO28_ADC2)
unnamed: J2.8, U1.33 (AGND)
unnamed: J2.9, U1.32 (GPIO27_ADC1)
unnamed: J2.10, U1.31 (GPIO26_ADC0)
unnamed: J2.11, U1.30 (RUN)
unnamed: J2.12, U1.29 (GPIO22)
unnamed: J2.14, U1.27 (GPIO21)
unnamed: J2.15, U1.26 (GPIO20)
unnamed: J2.16, U1.25 (GPIO19)
unnamed: J2.17, U1.24 (GPIO18)
unnamed: J2.19, U1.22 (GPIO17)
unnamed: J2.20, U1.21 (GPIO16)
unnamed: J3.1, U1.43 (SWDIO)
unnamed: J3.3, U1.41 (SWCLK)


Board: 2 copper layers, 43.0 x 65.0 mm, 4 parts (0 on the bottom side), 36 nets.

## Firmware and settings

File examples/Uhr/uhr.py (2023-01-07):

import board
import neopixel
from adafruit_pixel_framebuf import PixelFramebuffer
import time
from microbmp import MicroBMP
import rtc

import socketpool
import wifi
import adafruit_ntp


pixel_pin = board.GP21
pixel_width = 32
pixel_height = 8

pixels = neopixel.NeoPixel(
    pixel_pin,
    pixel_width * pixel_height,
    brightness=0.1,
    auto_write=False,
)

pixel_framebuf = PixelFramebuffer(
    pixels,
    pixel_width,
    pixel_height,
    orientation='VERTICAL',
    alternating=True,
    reverse_x=False,
)



text = "Willkommen im KidsLab! Nächster Kurs: Donnerstag... offener Donnerstag"





def bmp_to_screen(img, screen, x0, y0):
    for y in range(img.DIB_h):
        for x in range(img.DIB_w):
            screen.pixel(x + x0, y + y0, img[x, y])

def show_bmp(screen,filename,x0 = 0, y0 = 0):
    bmp = MicroBMP().load(filename)
    bmp_to_screen(bmp,screen, x0, y0)
    screen.display()


def show_time(screen):
    zeit = rtc.RTC().datetime

    show_bmp(screen,"img/"+str(zeit[3])[0:1]+".bmp",11,1)
    show_bmp(screen,"img/"+str(zeit[3])[1:2]+".bmp",16@,1)
    show_bmp(screen,"img/"+str(zeit[4])[0:1]+".bmp",22,1)
    show_bmp(screen,"img/"+str(zeit[4])[1:2]+".bmp",27,1)





wifi.radio.connect("", "")


pool = socketpool.SocketPool(wifi.radio)
ntp = adafruit_ntp.NTP(pool, tz_offset=0)
rtc.RTC().datetime = ntp.datetime



while True:

    show_time(pixel_framebuf)

    show_bmp(pixel_framebuf,"birne1.bmp")
    time.sleep(1)
    show_bmp(pixel_framebuf,"birne2.bmp")
    time.sleep(1)
    show_bmp(pixel_framebuf,"birne3.bmp")
    time.sleep(1)
    show_bmp(pixel_framebuf,"birne4.bmp")
    time.sleep(1)


    # state":{"open":true

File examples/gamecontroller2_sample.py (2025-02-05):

import board
import neopixel
import time
import random

# Configure the matrix
PIXEL_PIN = board.GP12
PIXEL_WIDTH = 5
PIXEL_HEIGHT = 5
NUM_PIXELS = PIXEL_WIDTH * PIXEL_HEIGHT
BRIGHTNESS = 0.05

pixels = neopixel.NeoPixel(PIXEL_PIN, NUM_PIXELS, brightness=BRIGHTNESS, auto_write=False)

def xy_to_index(x, y):
    """Convert x,y coordinates to pixel index"""
    if y % 2 == 0:
        return y * PIXEL_WIDTH + x
    else:
        return y * PIXEL_WIDTH + (PIXEL_WIDTH - 1 - x)

def rainbow_cycle(wait):
    """Rainbow animation across all pixels"""
    for j in range(255):
        for x in range(PIXEL_WIDTH):
            for y in range(PIXEL_HEIGHT):
                idx = xy_to_index(x, y)
                rc_index = (x * 256 // PIXEL_WIDTH) + j
                pixels[idx] = wheel(rc_index & 255)
        pixels.show()
        time.sleep(wait)

def wheel(pos):
    """Generate rainbow colors"""
    if pos < 85:
        return (pos * 3, 255 - pos * 3, 0)
    elif pos < 170:
        pos -= 85
        return (255 - pos * 3, 0, pos * 3)
    else:
        pos -= 170
        return (0, pos * 3, 255 - pos * 3)

def ripple(color, wait):
    """Create a ripple effect from center"""
    center_x = PIXEL_WIDTH // 2
    center_y = PIXEL_HEIGHT // 2
    
    for distance in range(max(PIXEL_WIDTH, PIXEL_HEIGHT)):
        pixels.fill((0, 0, 0))
        for x in range(PIXEL_WIDTH):
            for y in range(PIXEL_HEIGHT):
                if abs(x - center_x) + abs(y - center_y) == distance:
                    pixels[xy_to_index(x, y)] = color
        pixels.show()
        time.sleep(wait)

def random_sparkle(wait):
    """Random twinkling effect"""
    pixels.fill((0, 0, 0))
    for _ in range(NUM_PIXELS // 3):
        i = random.randint(0, NUM_PIXELS - 1)
        pixels[i] = (random.randint(0, 255), random.randint(0, 255), random.randint(0, 255))
    pixels.show()
    time.sleep(wait)

def snake(color, wait):
    """Snake moving through the matrix"""
    for i in range(NUM_PIXELS):
        pixels.fill((0, 0, 0))
        pixels[i] = color
        if i > 0:
            pixels[i-1] = (color[0]//4, color[1]//4, color[2]//4)
        pixels.show()
        time.sleep(wait)

# Main animation loop
while True:
    # Rainbow cycle
    for _ in range(2):
        rainbow_cycle(0.01)
    
    # Ripple effect
    for _ in range(5):
        ripple((0, 0, 255), 0.1)  # Blue ripple
        ripple((255, 0, 0), 0.1)  # Red ripple
        ripple((0, 255, 0), 0.1)  # Green ripple
    
    
    # Random sparkles
    for _ in range(50):
        random_sparkle(0.05)
    
    # Snake animation
    for _ in range(3):
        snake((255, 0, 0), 0.1)  # Red snake
        snake((0, 255, 0), 0.1)  # Green snake
        snake((0, 0, 255), 0.1)  # Blue snake

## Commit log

2022-05-11 added outline as footprint to be edited for working edge cout
2022-05-11 same as before
    [kids-lab-bulb.dxf, kidslab-lamp.kicad_pcb, kidslab-lamp.kicad_sch]
2022-05-18 new pcb outline, added frisbee footprints, smaller PCB, added arrow footprints etc.
    [Pico.skp, Test.kicad_pcb, Test.kicad_sch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]
2022-05-19 added 3.3V rail, replaced GND on bottom with 5V rail added Servo pin header
    [kidslab-lamp.kicad_pcb, kidslab-lamp.kicad_sch]
2022-05-22 Design der Rückseite
2022-05-22 added backside art, LED, and frontside kidslab logo
    [kidslab-lamp.kicad_pcb, kidslab-lamp.kicad_sch]
2022-05-23 finished design, further checks have to be done before ordering
    [Grove Connector (sit).STEP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]
2022-09-11 updated PCB with requested changes
    [kidslab-lamp.kicad_pcb, kidslab-lamp.kicad_sch]
2022-09-12 cleared schematics and exported pdf, fixed some routing issues, generated gerber files
    [kidslab-lamp-B_Cu.gbl, kidslab-lamp-B_Cu.gbr, kidslab-lamp-B_Mask.gbr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]
2022-12-13 Update README.md
    visitenkarten infos 👍
2023-11-03 adding components to schematic
    [Pico.skp, Test.kicad_pcb, Test.kicad_sch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]
2023-11-04 adding layout
    [Grove Connector 90.STEP, Grove Connector.STEP, SMD3535 RGB.stp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]
2023-11-04 fixing some silkscreen issues
    [bom.csv, components-sheet.kicad_sch, designators.csv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]
2023-11-15 fixing component attributes, moving v1 gerber files
    [bom.csv, components-sheet.kicad_sch, designators.csv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]
2023-12-16 ploted schematics
    [kidslab-lamp-B_Cu.gbr, kidslab-lamp-B_Mask.gbr, kidslab-lamp-B_Paste.gbr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]
2024-01-05 adding coordinate system for imu, changing imu part, changing touch resitros to pull down
    [bom.csv, designators.csv, positions.csv]
2024-01-08 adding polarity information to silkscreen
    [bom.csv, designators.csv, kidslab-lamp.kicad_pcb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]
2024-05-13 die blinkenlights fliege als firmware
2024-10-06 adding new project with USB-C connector and 3V3 LDO
    [nerdYcontroller.kicad_pcb, nerdYcontroller.kicad_sch, power-and-usb.kicad_sch]
2024-10-07 Adding components to USB-C and 3V3 LDO
    [power-and-usb.kicad_sch]
2024-10-24 Adding kicad-nerdYController
    [led_matrix.kicad_sch, nerdYcontroller.kicad_sch, peripherals.kicad_sch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]
2024-12-27 firmware für platinen ohne imu
2025-01-08 Adding KiCad files for first controller production.
    [bom.csv, designators.csv, kids-lab-bulb.dxf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]
